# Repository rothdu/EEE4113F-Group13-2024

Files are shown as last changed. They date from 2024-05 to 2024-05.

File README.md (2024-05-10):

# UCT EEE4113F Group 13 2024

## Project description

This project involved the production of a camera-trap module for research on red-winged starlings at the University of Cape Town. The camera trap was designed to be stationed at the bird nests. Core requirements were motion-triggered photography, long-lasting battery life, and access to the module without disturbing the nests.

## Navigating the repository

circuit-schematics: shematics for the electronic hardware design
final-report: latex source code for the final project report
literature-review: latex source code for the project liteature review
firmware: firmware source code for the firmware development process and final implementation
sample-code: some sample code used to test the device hardware

## Contributing

This project will be drawn to a close after 15 May 2024.

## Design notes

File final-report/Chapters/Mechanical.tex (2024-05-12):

% ----------------------------------------------------
% Literature Review
% ----------------------------------------------------
\documentclass[class=report,11pt,crop=false]{standalone}
\input{../Style/ChapterStyle.tex}
\input{../FrontMatter/Glossary.tex}
\begin{document}
\ifstandalone
\tableofcontents
\fi
% ----------------------------------------------------
\chapter{ Mechanical Casing and Housing (MRBMAT004)\label{ch:mechanical}}
% \epigraph{}%
    % {\emph{---Carl Sagan}}
% \vspace{0.5cm}
% ----------------------------------------------------

% Before we even start on the first point, we should have a brief intro to talk about what it is we are doing. 
% Before this in chapter 1 will be our problem statement. 
% This is what I suggest: This literature delves into previous research articles pertaining to wildlife monitoring and related fields to better understand the approach that needs to be taken to design an effective camera module. This review will look into existing solutions (both the successes and failures). Data acquisition methods were also investigated. Integration of camera traps with IoT, sensing and power supply requirements were researched as well as looking into camera traps being situated in an urban setting with the risk of theft or damage from weather conditions. 
%Chapter 
%Mechanical Casing and Housing
\section{Introduction}
This section covers the mechanical case designs crafted for the the remote surveillance system deployed at the the Starlings’ nests located within the University of Cape Town for Sally who works at the Fitz Patrick Institute. The goal for this project was enhance nest surveillance through innovative technological solutions. These enclosures serve as the protective shell for our electronic components, safeguarding them against the elements while ensuring optimal functionality. By providing robust protection against environmental factors such as moisture, dust, and temperature fluctuations, the mechanical cases play a crucial role in the reliability and longevity of the surveillance system.
\newline

The surveillance system addresses existing challenges and gaps in current methods of monitoring bird nests by providing real-time data collection, minimizing disturbance to nesting birds, and enabling remote observation capabilities. Traditional nest monitoring methods often rely on manual observation, which can be time-consuming, labour-intensive, and disruptive to nesting birds. Our system offers a non-invasive alternative that allows researchers to gather valuable data without causing undue stress to the bird population.
\newline

The mechanical cases discussed in this section will house the Transmitter and Receiver circuitry systems that aim to solve the surveillance of the nests. This section discusses the design decisions, material choices and processes undertaken to realise the ‘final’ prototype. 
A comprehensive breakdown of the design processes, material choices, and iteration phases involved in the development of the mechanical cases. Exploring the intricacies of each design iteration, discussing the rationale behind design decisions and the challenges encountered during the prototyping process. Additionally, results for, testing and evaluation efforts, offering insights into the performance and effectiveness of the 'final' prototype. Finally, we will draw conclusions based on our findings and discuss potential avenues for future research and development in the field of avian monitoring technology.
\newline

\subsection{Requirements, Specifications, and Acceptable Prototype}
•	Size: 6x6x8cm\newline
•	Receiver case: handheld capability or mounting option\newline
•	Transmitter and receiver cases: safely house the sensor and power module circuits.\newline
•	Circuit protection from environmental conditions and theft prevention. \newline
•	Ease of access for maintenance and user experience.\newline
•	Compatibility with monitoring equipment.\newline
\newline

\section{Design Process}
\subsection{First Iteration Prototype}
The first iteration of the prototype was a simple rectangular box. During the initial stages of the design process, there was limited scope and clarity regarding the project requirements, prompting the development of a basic prototype to initiate discussions with stakeholders.
\newline

However, upon further refinement of the project specifications, it became evident that the initial rectangular design did not align with Sally's requirements, particularly in terms of size. The dimensions of the prototype were arbitrary and did not meet the specified 6x6x8cm dimensions. This discrepancy highlighted the need for clearer communication and adherence to design specifications from the onset of the project.
\newline

Additionally, the choice of PLA material for the prototype was based on availability, without consideration of alternative materials such as PETG, which offers superior properties for this application. The transition to PETG was later explored to address concerns related to material durability and performance.
\newline

One notable feature of the first iteration was the inclusion of a sliding mechanism for the open/close function. While this mechanism provided ease of access to the internal components, it posed challenges in terms of sealing effectiveness against moisture, dust, and water ingress. This limitation underscored the importance of robust sealing methods to ensure environmental protection and longevity of the electronic components housed within the enclosure.
\newline

Furthermore, the rectangular shape of the prototype presented challenges in airflow management, potentially leading to airflow turbulence or restrictions within the enclosure. While passive cooling solutions could be employed, such as ventilation holes, the design lacked provisions for active cooling mechanisms, which may be necessary to maintain optimal operating temperatures for sensitive electronics.
\newline

Despite these limitations, the rectangular design demonstrated efficiency in space utilization, offering maximum volume for component placement and organization. Moreover, its geometric simplicity facilitated ease of fabrication, reducing manufacturing complexity and costs associated with more intricate shapes.
\newline

Overall, the first iteration prototype served as a valuable learning experience, highlighting the importance of clear requirements definition, material selection, sealing methods, and considerations for airflow management in the design process. These insights informed subsequent iterations towards the development of a more refined and functional final prototype.
\newline

\subsection{Second Iteration}
The second iteration resembled a pitched roof house. This design idea was perfect until the size constraints were brought forth. Secondly, the pitched roof also limits and reduces the size of the already small dimensions of the specifications given by Sally: 6x6x8cm. 
\newline
This design had ventilation holes and forced cooling using a fan was considered. This fan would require a timer and trigger signal. This design had better airflow management as it promoted natural convection through the ventilation peaks at the peak without the need for additional cooling. The pitched roof enclosures blend seamlessly into outdoor environments, providing camouflage and enhancing the overall aesthetic appeal. However, concerns arose regarding the practicality of this design, particularly regarding size constraints and the need for additional cooling mechanisms as a fan would put added strain on the power supply and increase power losses.
\newline

\subsection{Material used}
% https://all3dp.com/2/plavsabsvspetgdifferencescompared/#google_vignette  
PLA, ABS and PETG are the most popular and readily available filaments out there. However, they are not equally suitable for every printing job as they have different qualities. All these comparisons were found from this non-scholarly article: https://all3dp.com/2/plavsabsvspetgdifferencescompared/#google_vignette
\newline

\subsubsection{PLA (Polylactic Acid)}
PLA is a widely used 3D printing material known for its ease of printing and low cost. Derived from renewable sources like corn starch, PLA is considered environmentally friendly, although it is more accurately described as industrially compostable rather than biodegradable. Its benefits include easy printing with no clogging issues, low print temperature, and affordability. However, PLA tends to deform or melt in high heat, making it unsuitable for heat resistant applications. It is also brittle and less sturdy compared to materials like ABS or PETG, making it better suited for aesthetic uses rather than mechanical ones.
\newline

\subsubsection{ABS (Acrylonitrile butadiene styrene)}
ABS (Acrylonitrile Butadiene Styrene) is a durable thermoplastic commonly used in 3D printing, injection molding, and machining. While it offers increased durability and resistance to water compared to PLA, it can emit unpleasant fumes during printing. ABS is known for its strength, toughness, and heat resistance, making it suitable for everyday items. However, it may degrade over time when exposed to prolonged moisture, and it is prone to dust accumulation. Despite its drawbacks, ABS can be easily finished post printing using acetone, making it suitable for aesthetic prints.
\newline

\subsubsection{PETG (Polyethylene terephthalate glycol)}
PETG is a popular choice for applications requiring food safety due to its excellent material properties. While it offers superior water resistance compared to PLA and ABS, printing PETG can be challenging due to its tendency to string during printing. PETG is known for its durability, impact resistance, and UV resistance, making it suitable for outdoor applications. However, it is prone to scratching and requires high printing temperatures, which contribute to stringing issues. Overall, PETG is widely regarded as a food safe filament with excellent mechanical properties.
\newline

Comparisons
\begin{table}[h]
\centering
\begin{tabular}{|>{\raggedright\arraybackslash}p{0.25\linewidth}|>{\raggedright\arraybackslash}p{0.25\linewidth}|>{\raggedright\arraybackslash}p{0.25\linewidth}|>{\raggedright\arraybackslash}p{0.25\linewidth}|}
\hline
 & \textbf{PLA} & \textbf{ABS} & \textbf{PETG} \\ \hline
Temperature & 180-220°C & 210-250°C & 220-250°C \\ \hline
Heated Bed Required & No & 210-250°C & 220-250°C \\ \hline
Enclosure & Does not require an enclosure & ABS is quite susceptible to drafts. Would benefit from an enclosure, to prevent warping and cracking & Does not require an enclosure \\ \hline
Post Processing & Filling, sanding, and priming are the primary methods. There are no safe chemical agents. & Easy to smooth out ABS using acetone & Ethyl acetate can be used to smooth PETG. Filling, sanding, and priming also work \\ \hline
Strength and Durability & Low-to-medium strength filament given its low heat and chemical resistance. & Medium-to-high strength filament, as it will sooner bend than break and has a higher impact, heat, and chemical resistance than PLA. & Medium-to-high strength filament. Mostly like ABS but is superior in strength \\ \hline

\end{tabular}
\end{table}

\begin{table}
    \centering
    \begin{tabular}{|>{\centering\arraybackslash}p{0.25\linewidth}|>{\centering\arraybackslash}p{0.25\linewidth}|>{\centering\arraybackslash}p{0.25\linewidth}|>{\centering\arraybackslash}p{0.25\linewidth}|} \hline 
Toxicity and Odour & Low odour and no toxicity & Has considerable odour and toxicity. & No odour or toxicity \\ \hline
Best Use Cases & Applications that do not have any specific functional requirements. & Often used in functional items that are used frequently or need to be durable. E.g. Drone frame & Excellent for items in contact with food and UV exposure, great for functional parts \\ \hline
    \end{tabular}
    \caption{3D prints filaments Comparison}
    \label{tab:my_label1}
\end{table}

\subsection{Dual and Single enclosure considerations}
In evaluating enclosure design options, a thorough analysis reveals the nuanced advantages of single and dual enclosure configurations. Single enclosures offer notable benefits such as efficient space utilization, simplified installation procedures, streamlined maintenance workflows, and potential cost savings due to component consolidation. However, they also pose challenges in thermal management, necessitating meticulous attention to airflow dynamics and heat dissipation strategies. Furthermore, comprehensive dustproofing measures are imperative to mitigate the risk of contamination and ensure long-term reliability.
\newline

Conversely, dual enclosure setups introduce unique advantages that contribute to the overall resilience and adaptability of the surveillance system. The modular nature of dual enclosures facilitates enhanced system flexibility, allowing for seamless component replacement, upgrades, or reconfigurations without disrupting the entire system. Moreover, the isolation of components within separate enclosures minimizes the risk of interference or contamination, ensuring optimal performance and reliability. The redundancy provided by dual enclosures offers an added layer of security, ensuring continuous operation even in the event of enclosure failure or malfunction.
\newline

Additionally, the customization potential inherent in dual enclosures enables tailored solutions to meet specific application requirements or environmental conditions. From optimized thermal management strategies to tailored dustproofing mechanisms, dual enclosures provide a versatile platform for finetuning system performance and resilience. By segregating components based on thermal characteristics, dual enclosures facilitate more effective heat distribution and dissipation, mitigating the risk of localized overheating and component degradation.
\newline

Furthermore, the independent sealing mechanisms of dual enclosures simplify dustproofing efforts, allowing for targeted measures to prevent dust ingress and contamination. By customizing dust filters and seals for each enclosure, the overall reliability and longevity of the surveillance system are enhanced, ensuring consistent performance even in harsh or dusty environments.

\subsection{Shape Considerations}
Each shape offers unique advantages and disadvantages, influencing space efficiency, aerodynamics, aesthetics, manufacturing complexity, and application-specific requirements.
\newline

Rectangular enclosures excel in efficient space utilization and ease of manufacture, making them suitable for accommodating complex electronic assemblies. However, they may lack optimal aerodynamics and aesthetic appeal compared to other shapes.
\newline

Cylindrical enclosures distribute stress more evenly and offer 360-degree access, making them robust and versatile for various applications. Yet, they may suffer from space inefficiency and manufacturing complexity.
\newline

Tapered or sloped enclosures prioritize improved aerodynamics and aesthetic appeal, optimizing space utilization while posing challenges in design complexity and manufacturing.

\section{Final Design Prototype}
The implementation of two separate electronic enclosure designs for the transmitter and receiver subsections was pivotal in addressing thermal concerns and meeting the distinct requirements of each subsystem. This separation not only improved temperature management but also allowed for increased airflow within each enclosure. Furthermore, considering that the transmitter and receiver subsystems are exposed to different environmental conditions and demand varied parameters for system longevity, this tailored approach ensured optimal performance and durability.
\newline

\subsection{Transmitter Case}
The final design for the mechanical cases for the transmitter subsection was chosen to be a rectangular box, carefully crafted to optimise functionality and environmental protection. It consisted of ventilation holes strategically placed to promote aeration and better airflow management, the design aimed to maintain optimal operating conditions for the enclosed components. Four vents were positioned at the base of the enclosure, each with a 5mm diameter and spaced 30mm apart, allowing air to enter from distinct locations. To prevent ingress of pests, debris, and dust, mesh screen filters covered these vents, while also minimizing the entry of water.
\newline

Four rectangular extrusions, situated 9mm above the base of the box, provided mounting or adhesive points for the Vero boards. This elevated placement reduced contact with any water that might enter through the base vents, ensuring the integrity of the components. Moreover, this design allowed for sufficient space for cool air to circulate around the boards.
\newline
\newline
\begin{figure}[H]
    \centering
    
    \caption{Solid works sensor design}
    \label{fig:enter-label3}
\end{figure}

To further enhance thermal management, aluminium heatsinks were strategically placed next to resistive and heat prone components. The orientation of the heatsink fins facing vertically upwards facilitated the natural convection process, whereby warm air rises. This directed the heat away from the components and towards the top of the enclosure. This is because warm air has lower density than cold air hence it rises. 
\newline

Additionally, three vents on either side of the box were incorporated to facilitate the removal of warm air from within the enclosure. This prevented the accumulation of warm air and the formation of a low-pressure cell, ensuring efficient airflow throughout the enclosure.
\newline

To tightly seal the enclosure a lid screw was used to minimise dust and water which was better than the sliding open/close mechanism used before.
\newline
For water and moisture management, a desiccant, silica gel was used to remove or absorb moisture from the electronic enclosure.
\newline

\subsection{Safety mechanisms and waterproof}
Mounting the rectangular enclosure is crucial for both practical functionality and ensuring safety and security. By rigidly attaching the enclosure to a stable structure like a wall or pole, it reduces the risk of unauthorized access to its internal components. This means it is much harder for people without permission to tamper with or steal the system. The act of mounting also acts as a strong deterrent against theft or vandalism, as it makes it clear that the system is secure and not easily removable. Additionally, securely mounting the enclosure ensures it can withstand external forces like wind or impact, making it more durable. It also helps the system comply with safety regulations, ensuring it meets industry standards. Adding features like tamper-resistant mechanisms further enhances security, making it even harder for unauthorized access. Overall, mounting the rectangular enclosure not only serves practical purposes but also plays a vital role in protecting the system and ensuring it functions effectively for a long time.
Mounting the enclosure was deemed a superior safety and security measure, particularly due to the elevated and often remote locations of Starlings' nests, where human access is infrequent. Opting for mounting over traditional locking mechanisms offers a practical solution, ensuring the system's protection without the complexities associated with locks. By rigidly attaching the enclosure to a stable structure, such as a wall or pole, the system's integrity is effectively preserved, mitigating the risk of tampering or theft. This approach not only enhances security but also aligns with the practical constraints of the surveillance environment, where accessibility is limited.

\begin{figure}[H]
    \centering
    
    \caption{Starlings bird Nest Position}
    \label{fig:enter-label2}
\end{figure}

In the ongoing development of the electronic enclosure, a transition has been made from a sliding open/close mechanism to a lid screw configuration. This upgrade aims to provide a more robust closure, effectively minimizing the intrusion of dust and water, while also enhancing security for the enclosed electronics.
\newline

% \newline
\begin{figure}[H]
    \centering
    
    \caption{SolidWorks lid design}
    \label{fig:enter-label3}
\end{figure}

Additionally, to address water and moisture management within the enclosure, silica gel desiccant packs have been integrated into the design. These packs serve as an effective solution for moisture absorption, ensuring the internal environment remains dry and conducive to the optimal functioning of the electronic components. Furthermore, the potential addition of cotton alongside the silica gel desiccant packs can provide an extra layer of moisture protection, especially in environments with high humidity levels or where condensation may occur. Cotton's ability to absorb excess moisture and function as a buffer between electronic components and desiccant packs offers additional assurance against moisture infiltration.
\newline

\subsubsection{Material of Choice}
PETG was the material of choice for the enclosure. PETG offers UV resistance, ensuring the enclosure's structural integrity and optical clarity under prolonged sunlight exposure. Its weather resistance enables it to withstand extreme temperatures, both cold and hot, without compromising its mechanical properties. PETG's strength and loadbearing capacity make it suitable for housing electronic components securely. Importantly, PETG is non-toxic and does not emit harmful gases, aligning with your sustainability goals. Additionally, its recyclable nature promotes responsible material usage, further enhancing the project's sustainability. 
\newline

There were two enclosures designed for the transmitter subsection housing, one for the power module and the other for the sensing circuitry discussed in the other two sections of the report. The dual enclosure method was implemented based on the advantages discussed above. Moreover, it allowed for modular design for each of the systems’ requirements. 
\newline

The power enclosure had all the design considerations discussed above: a lid screw, four vents at the bottom, three on either side of the box, four extrusions for Veroboard, and lastly four exterior extrusions with holes for mounting.
\newline
\begin{figure}[H]
    \centering
    
    \caption{The Power system enclosure}
    \label{fig:enter-label3}
\end{figure}

%%%add the power house
 
The sensing circuitry housing had the same design as the housing for power and had additional openings for the camera sensor, 5 PIR sensors and the 2 LDRs, so that surveillance can be achieved remotely while the housing is mounted. The housings are to be mounted close to the nests which would be easy given where the nests are on campus. 
 %%add thiyashans hous

\begin{figure}[H]
    \centering
    
    \caption{The Sensor system enclosure}
    \label{fig:enter-label4}
\end{figure}

\subsection{Receiver Case}
The receiver module material was chosen to be ABS, since it is durable and can be used for consumer daily needs. ABS’ smooth texture and durability and impact resistance made it a suitable material choice for the handheld receiver module.
\newline

The enclosure design included a carefully cutout area to display the LCD output, with a detachable clip side serving as a convenient access point for buttons, eliminating the need for enclosure disassembly. 
\newline

Additionally, a removable latch-sliding mechanism provided port access and simplified battery replacement, as the battery was located on the sliding mechanism side. The generous opening on the sliding mechanism side facilitated effortless battery changes. Prioritizing portability, the enclosure was designed to be handheld, with a compact size ensuring easy readability of LCD display information. This module was bought and had to be assembled and cut the LCD screen part. The removable clip side for the button side made this case attractive as it would be easier to cut holes on the clip or just remove the clip when wanting to access and interface with the buttons. The screw assembled and joined case ensured secure assembly, featuring extrusions for Veroboard placement and a divider allowing for the partitioning of different circuit systems within the enclosure.
\newline

The receiver module did not have specific dimensions but was required to accommodate an 8x4cm LCD area and house the receiver circuitry and its power requirements. This was a single enclosure, and was chosen for the reasons already outlined above, such as efficient space utilization, simplified installation procedures, streamlined maintenance workflows, and potential cost savings. The enclosure design allowed for better airflow, with the removable latch sliding mechanism and LCD cutout contributing to ventilation. Storage conditions were expected to be room temperature, with user requirements limited to handheld, LCD display output and button access, while ensuring circuit integrity and weight support.

\begin{figure}[H]
    \centering
    
    \caption{The receiver enclosure}
    \label{fig:enter-label5}
\end{figure}

\section{Acceptable Test Procedures}
 
1. Material Durability and Impact Resistance Test:
 Drop tests were conducted from various heights to assess the durability and impact resistance of the ABS and PETG materials. Observations were made for any signs of damage, cracking, or deformation after each drop test. None were found so passed. 
 \newline

2. Ventilation and Airflow Test:
    The enclosure designs with ventilation holes and extrusions were 3D printed. Temperature and humidity sensors were used to measure airflow and temperature distribution within the enclosures.
    The effectiveness of the ventilation system in maintaining optimal operating conditions for enclosed components was evaluated. The system integration with the sensing subsystem could not be done due to time constraints so this test could not be performed, hence undeterminable.
    \newline

3. Weather Resistance Test:
    The 3D-printed enclosures were subjected to temperature and humidity variations in a controlled environment. Exposure to UV light was done by placing the enclosures on the window for days. The enclosures were assessed for any signs of degradation, discoloration, or moisture ingress after exposure. None were found so passed.
    \newline

4. Lid Screw Seal Integrity Test:
    The enclosures were 3D printed with lid screw mechanisms. The lid and housing were mated on SolidWorks to ensure that they fit together through simulation. The lid was successfully screwed to the enclosure, although it had to be cut since Solidworks scaled the enclosures. Passed.
    \newline

5. Moisture Management Test:
 Silica gel desiccant packs and cotton were placed inside the 3D-printed enclosures. Moisture levels inside the enclosures were monitored over time using moisture indicators. The effectiveness of moisture absorption and management by the desiccant packs and cotton was verified. The system integration with the sensing subsystem could not be done due to time constraints so this test could not be performed, hence undeterminable.
\newline

6. Portability and Handheld Use Test:
The 3D-printed enclosures were assembled, and the bought design for handheld use was assessed. The comfort and ease of handling were evaluated, ensuring easy access to buttons and readability of the LCD display. Passed.
\newline

7. Assembly and Disassembly Test:
    The 3D-printed enclosures were assembled and disassembled multiple times to assess the ease of assembly and accessibility to internal components. Wear or damage to the enclosure components during assembly and disassembly was checked. Passed
    \newline

8. Mounting and Security Test:
 The 3D-printed enclosures were attached to stable structures using mounting brackets or adhesive mounts. Force or pressure was applied to the mounted enclosures to simulate external impacts, verifying their stability and security. Passed. 
 \newline

9. Functionality and Compatibility Test:
Electronic components and power sources were installed inside the 3D-printed enclosures. The functionality of the LCD display, buttons, and other components was evaluated to ensure proper operation. Compatibility with the specified electronic components and power requirements was verified.
Failed. The enclosures were scaled down by the Prusa slicer and were not the same dimensions as given on solid works, hence the printed enclosures were small, and the lid had to be cut as it was not scaled to fit the small enclosures. 
\newline

% ----------------------------------------------------
\ifstandalone
\bibliography{../Bibliography/References.bib}
\printnoidxglossary[type=\acronymtype,nonumberlist]
\fi
\end{document}
% ----------------------------------------------------

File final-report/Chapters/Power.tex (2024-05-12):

% ----------------------------------------------------
% Literature Review
% ----------------------------------------------------
\documentclass[class=report,11pt,crop=false]{standalone}
\input{../Style/ChapterStyle.tex}
\input{../FrontMatter/Glossary.tex}
\begin{document}
\ifstandalone
\tableofcontents
\fi
% ----------------------------------------------------
\chapter{ Power Submodule
(PRMRUV001)\label{ch:literature}}
\section{Power Submodule}

In the submodule, it will detail the supply of power to the entire system as a whole. It serves as the heartbeat of the project and is very important. It deals with in a broader scope, the charging and storage of power that can be consumed, as well voltage regulation to a voltage that is suitable for the other submodules that need to draw power.

\section{Requirement Analysis}

In order to design an effective power submodule, analysis of what needs to be achieved in this submodule needs to be carried out extensively. Meeting the user’s requirements are the main objectives. However, in order to meet these requirements well, functional requirements and specifications of the proposed solution needs to be detailed. This can be found below.

\subsection{User Requirements}

These requirements are set out by the client, Sally. In order for the submodule to be a success it would need to meet the requirements. 

\begin{table}
\centering

\begin{tabular}{|>{\raggedright\arraybackslash}p{0.2\linewidth}|>{\raggedright\arraybackslash}p{0.8\linewidth}|}
\hline
\textbf{UR01} & \textbf{Grid Independent} \\
\hline
\textbf{Requirement} & Sally requires the device to charge without the grid mains power supply. \\
\hline
\textbf{Description} & The power system is the heartbeat of the camera trap device, and its awkward placements in nests make it difficult for the device to always be charged using the grid main power supply. Hence, Sally’s requirement for the device to be charged and powered using an alternative power supply method. \\
\hline
\textbf{Refined by} & FR01 \\
\hline

\end{tabular}

\end{table}

\begin{table}
\centering

\begin{tabular}{|>{\raggedright\arraybackslash}p{0.2\linewidth}|>{\raggedright\arraybackslash}p{0.8\linewidth}|}
\hline
\textbf{UR02} & \textbf{Reliability} \\
\hline
\textbf{Requirement} & Sally requires a device that has a reliable power supply.  \\
\hline
\textbf{Description} & It was made clear that the monitoring of these birds is very important and so is the data recorded. Hence, it is vitally important that the device continuously has good reliable power supply to operate to avoid data capturing loss. \\
\hline
\textbf{Refined by} & FR02 \\
\hline

\end{tabular}

\end{table}

\begin{table}
\centering

\begin{tabular}{|>{\raggedright\arraybackslash}p{0.2\linewidth}|>{\raggedright\arraybackslash}p{0.8\linewidth}|}
\hline
\textbf{UR03} & \textbf{Sizing} \\
\hline
\textbf{Requirement} & Sally requires the device to be light and compact. \\
\hline
\textbf{Description} & The starling birds are very sensitive and particularly do no like foreign objects in their space. Furthermore, the nests that are to be monitored are small and light. Hence, the need for the Power submodule to be as light and compact as possible. \\
\hline
\textbf{Refined by} & FR03 \\
\hline

\end{tabular}

\end{table}

\subsection{Functional Requirements}

These requirements are outlined by the designer in order to make the users requirements more detailed. This in turn makes the submodule more coherent and lay out guidelines to follow so that the submodule can be a success.

\begin{table}
\centering

\begin{tabular}{|>{\raggedright\arraybackslash}p{0.2\linewidth}|>{\raggedright\arraybackslash}p{0.8\linewidth}|}
\hline
\textbf{FR01-1} & \textbf{Rechargeable Battery} \\
\hline
\textbf{Requirement} & The system battery needs to be able to support recharging from sources such as solar power. \\
\hline
\textbf{Refines} & UR01 \\
\hline
\textbf{Refined by} & UR01-S01 \\
\hline
\textbf{Verification} & N/A \\
\hline

\end{tabular}

\end{table}

\begin{table}
\centering

\begin{tabular}{|>{\raggedright\arraybackslash}p{0.2\linewidth}|>{\raggedright\arraybackslash}p{0.8\linewidth}|}
\hline
\textbf{FR01-2} & \textbf{Solar Panel} \\
\hline
\textbf{Requirement} & The system requires a solar panel as a form of solar power generation to charge the battery. \\
\hline
\textbf{Refines} & UR01 \\
\hline
\textbf{Refined by} & UR01-S02 \\
\hline
\textbf{Verification} & ATP01 \\
\hline

\end{tabular}

\end{table}

\begin{table}
\centering

\begin{tabular}{|>{\raggedright\arraybackslash}p{0.2\linewidth}|>{\raggedright\arraybackslash}p{0.8\linewidth}|}
\hline
\textbf{FR02-1} & \textbf{Circuit Protection} \\
\hline
\textbf{Requirement} & The system battery needs to be able to support recharging from sources such as solar power. \\
\hline
\textbf{Refines} & UR01 \\
\hline
\textbf{Refined by} & UR01-S03 \\
\hline
\textbf{Verification} & ATP02, ATP03 \\
\hline

\end{tabular}

\end{table}

\begin{table}
\centering

\begin{tabular}{|>{\raggedright\arraybackslash}p{0.2\linewidth}|>{\raggedright\arraybackslash}p{0.8\linewidth}|}
\hline
\textbf{FR02-2} & \textbf{Voltage Conversion} \\
\hline
\textbf{Requirement} & The primary requirement is to provide a steady regulated output voltage of 5V. \\
\hline
\textbf{Refines} & UR02 \\
\hline
\textbf{Refined by} & UR02-S02 \\
\hline
\textbf{Verification} & ATP04 \\
\hline

\end{tabular}

\end{table}

\begin{table}
\centering

\begin{tabular}{|>{\raggedright\arraybackslash}p{0.2\linewidth}|>{\raggedright\arraybackslash}p{0.8\linewidth}|}
\hline
\textbf{FR02-4} & \textbf{Voltage ripple} \\
\hline
\textbf{Requirement} & The voltage ripple must be within acceptable limits, ideally as low as 100mV. \\
\hline
\textbf{Refines} & UR02 \\
\hline
\textbf{Refined by} & - \\
\hline
\textbf{Verification} & ATP05 \\
\hline

\end{tabular}

\end{table}

\begin{table}
\centering

\begin{tabular}{|>{\raggedright\arraybackslash}p{0.2\linewidth}|>{\raggedright\arraybackslash}p{0.8\linewidth}|}
\hline
\textbf{FR03-1} & \textbf{Size Restriction} \\
\hline
\textbf{Requirement} & The power submodule must fit in the casing dimensions stipulated in the casing submodule. \\
\hline
\textbf{Refines} & UR03 \\
\hline
\textbf{Refined by} & UR03-S01 \\
\hline
\textbf{Verification} & ATP06 \\
\hline

\end{tabular}

\end{table}

\section{Design Specifications}

In this chapter, we will specify how the requirements will be met as well as the engineering principles that will be used.

\begin{table}
\centering

\begin{tabular}{|>{\raggedright\arraybackslash}p{0.2\linewidth}|>{\raggedright\arraybackslash}p{0.8\linewidth}|}
\hline
\textbf{UR01-S01} & \textbf{Rechargeable Battery} \\
\hline
\textbf{Detail} & The batteries that will be used will be the 4.2V Lithium ion 18650 8800 mAh battery.  \\
\hline
\textbf{Refines} & FR01-1 \\
\hline
\textbf{Verification} & Battery selection in design choices section. \\
\hline

\end{tabular}

\end{table}

\begin{table}
\centering

\begin{tabular}{|>{\raggedright\arraybackslash}p{0.2\linewidth}|>{\raggedright\arraybackslash}p{0.8\linewidth}|}
\hline
\textbf{UR01-S02} & \textbf{Solar Panel} \\
\hline
\textbf{Detail} & The solar panel chosen must be able to provide minimum voltage required to charge the battery.  \\
\hline
\textbf{Refines} & FR01-2 \\
\hline
\textbf{Verification} & N/A \\
\hline

\end{tabular}

\end{table}

\begin{table}
\centering

\begin{tabular}{|>{\raggedright\arraybackslash}p{0.2\linewidth}|>{\raggedright\arraybackslash}p{0.8\linewidth}|}
\hline
\textbf{UR02-S01} & \textbf{Circuit Protection} \\
\hline
\textbf{Detail} & The submodule must include an over voltage protection circuit as well as well as a reverse polarity protection circuit in order to protect the components of the submodule.  \\
\hline
\textbf{Refines} & FR02-1 \\
\hline
\textbf{Verification} & ATP02, ATP03 \\
\hline

\end{tabular}

\end{table}

\begin{table}
\centering

\begin{tabular}{|>{\raggedright\arraybackslash}p{0.2\linewidth}|>{\raggedright\arraybackslash}p{0.8\linewidth}|}
\hline
\textbf{UR02-S02} & \textbf{Voltage Conversion} \\
\hline
\textbf{Detail} & The submodule will include a buck converter that will regulate the voltage down to a steady 5V.  \\
\hline
\textbf{Refines} & FR02-2 \\
\hline
\textbf{Verification} & ATP7 \\
\hline

\end{tabular}

\end{table}

\begin{table}
\centering

\begin{tabular}{|>{\raggedright\arraybackslash}p{0.2\linewidth}|>{\raggedright\arraybackslash}p{0.8\linewidth}|}
\hline
\textbf{UR03-S01} & \textbf{Sizing} \\
\hline
\textbf{Detail} & The submodule must fit in a casing of dimensions 60 x 60 x 80 mm \\
\hline
\textbf{Refines} & FR03-1 \\
\hline

\end{tabular}

\end{table}

\section{Acceptance Test Procedure (ATP’s)}

The acceptance test procedure will ensure that the design meets its intended performance. The procedure involves defining figures of merit, designing experiments to evaluate these metrics, and establishing acceptable performance standards.

\begin{table}
\centering

\begin{tabular}{| l  |l  |>{\raggedright\arraybackslash}p{0.3\linewidth}|>{\raggedright\arraybackslash}p{0.3\linewidth}|}
\hline
\textbf{ATP ID} & \textbf{ATP name} & \textbf{Figures of merit} & \textbf{Test} \\
\hline
\textbf{ATP01} & Solar Panels & Verify that the solar PV panels provide the minimum specified voltage for charging the battery packs.

  & Place Solar under various sun intensities and measure the produced voltages. \\
\hline
\textbf{ATP02} & Over Voltage Protection & Verify that the protection circuits work when they need to. & We can test this by applying a high voltage to the over voltage protection circuit. \\
\hline
\textbf{ATP03} & Reverse Polarity Protection. & Verify that the protection circuits work when they need to. & We can test this by applying a reverse bias current to the reverse polarity circuit. \\
\hline
\textbf{ATP04} & Voltage Regulation & This is about making sure the output voltage stays steady even when things change. We want to know if the converter can keep the voltage where we want it, no matter what's happening. & We'll suddenly change the load to see if the converter can keep the output voltage steady.

We'll watch the output voltage closely and check if it stays within a certain range of the desired voltage. \\
\hline
\textbf{ATP05} & Voltage ripple & We will perform this test to see that the voltage ripple is not exceeding our desired limits. & We can test this by connecting the output of the buck converter to the oscilloscope and using the measure function. \\
\hline
\textbf{ATP06} & Sizing & We will test to see that the power submodule Veroboard can fit in the casing. & We can test this by building our circuits on Veroboard and placing it in the casing. \\
\hline

\end{tabular}

\end{table}

\section{Design Choices}

In order to make design choices, we first have to understand how much power is required from the other submodules. This value is no more than 10 W.

\subsection{Battery choice}

There are multiple battery possibilities. However, we need to first calculate the required battery capacity in order to get a good fit. Using the table above we can allocate excess power and work of the required power being 20W. We can also assume we that we want the battery to operate for 12 hours, just enough time for the solar to start again.

We plan on using a five-battery pack rated at 4.2V each. The calculations are as follows:

Since the power required by the system was exaggerated, it is same to say that even with efficiency problems related to a battery, it would still be acceptable.

We can now analyse various batteries at similar rating as seen in the table below:

\begin{table}
\centering

\begin{tabular}{| l | l | l | l |}
\hline
  & \textbf{VRLA AGM Battery} & \textbf{Lead acid battery} & \textbf{Li-ion 18650} \\
\hline
\textbf{Type} & VRLA & LiFePO4  & Lithium ion \\
\hline
\textbf{Rated Voltage (V)} & 12 & 12 & 4.2 \\
\hline
\textbf{Rated Capacity (mAh)} & 7000 & 6000 & 8000 \\
\hline
\textbf{Size (mm)} & 151 x 65 x 95 & 152 x 65 x 97 & 65 x 20 x 20 \\
\hline
\textbf{Cost (R)} & 192 & 499 & 186 (Pack of 5) \\
\hline

\end{tabular}

\end{table}

 From the table above we can conclude our analysis on various types of batteries. With the VRLA AGM Battery, we can see that the rated capacity falls short of the required capacity as well as the rated voltage being too low. The lead acid battery follows the same suit and is very expensive making it a bad match. However, the Li-ion 18650’s seems to be the best match and the battery of choice. It falls withing the required capacity, has a rated voltage of 4.2V which when all are connected in series amount to 21V, and it is relatively affordable.

\subsection{Voltage Regulation}

The most crucial part of the power submodule is the voltage regulation. For this specific design, the other submodules only required a regulated voltage of 5V. This means that the voltage from the battery needs to be steeped down to that voltage of 5V. The various ways in which we can achieve that are detailed below:

\begin{table}
\centering

\begin{tabular}{| l | l | l | l |}
\hline
  & \textbf{L4940V5} & \textbf{CRE1S2405SC} & \textbf{Buck Converter} \\
\hline
\textbf{Input Voltage (V)} & 6.5 – 15 & 24 & 20 \\
\hline
\textbf{Output Voltage (V)} & 5 & 5 & 5 \\
\hline
\textbf{Output Current (A)} & 2.5 & 0.2 & Variable \\
\hline
\textbf{Complexity} & Easy & Easy & Complex \\
\hline
\textbf{Cost} & 28 & 57,07 & 20 \\
\hline

\end{tabular}

\end{table}

 From the table above we can make an inform decision in which methos we are going to use as our step-down regulator. We first analyse the L4940V5 voltage regulator, this does not fit well into the design because it outputs a max current that is high, and the input voltage will require a voltage divider in order for it to meet the specifications stated. The CRE1S2405SC is too expensive to use and also reflects no design thinking behind it. The buck converter using first principles can be tailored to fit any scenario and fits the design of the project best.

Hence, the buck converter using first principles is the best option.

\section{Power Submodule Design}

\subsection{Subsystem Block Diagram}

 \begin{figure}
     \centering
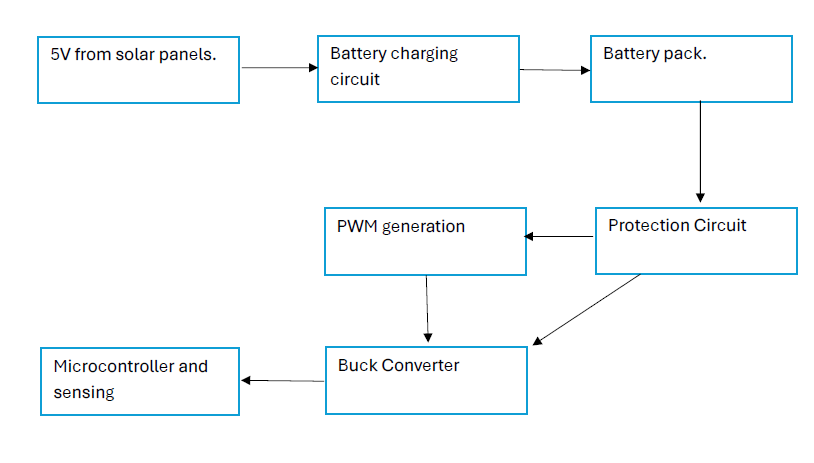
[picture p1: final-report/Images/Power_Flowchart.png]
     
     \caption{Flowchart of subsystem}
     \label{fig:enter-label}
 \end{figure}

\subsection{Pulse Width Modulation}

For this part of the submodule a 555 timer will be used to generate a pulse for the switch in the buck converter. The calculations of the parameters are as follows.

The circuit can be found below:
\begin{figure}
    \centering
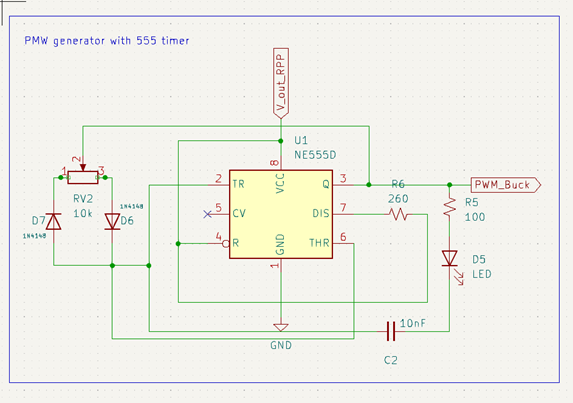
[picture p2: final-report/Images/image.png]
    
    \caption{PWM generator using a 555 timer.}
    \label{fig:enter-label}
\end{figure}

\subsection{Buck Converter (Voltage regulation)}

For this project, it is required that the designed system is efficient and can regulate the output voltage to 5V. The circuit parameters can be calculated, as shown below.

To explain how the selection of parameters occurred we will need to have a scenario/problem. 

Let's consider a scenario where we aim to design a DC-DC converter that converts a 20V DC input to a stable 5V DC output. We've chosen a switching frequency of 100 kHz. In addition, we want to maintain a current ripple of 0.5 and a voltage ripple of 10 mV for optimal performance.

\[Ripple\ current = \ \mathrm{\Delta}i_{L} = 0.5\ A\]

\[
{Therefore\ to\ find\ Inductor\ Value:}\]

\[
{L = \frac{V_{0}(1 - D)}{f_{s}\mathrm{\Delta}i_{L}}
}{Where:
}{V_{0} = 5V
}{D = \frac{V_{o}}{V_{in}} = \frac{5}{20} = 0.25
}{f_{s} = 100kHz}\]

\[Therefore\ from\ above\ the\ inductor\ value\ can\ be\ calculated:\]

\[
{L = \frac{5(1 - 0.25)}{(1000000)(0.5)} = 75\mu H}\]

\[Capacitor\ value\ is\ calculated\ using:\]

\[C = \frac{1 - D}{8L\left( \frac{\mathrm{\Delta}V_{o}}{V} \right)f^{2}} = \frac{1 - 0.25}{8(75\mu)\left( \frac{0.01}{5} \right)(100000)^{2}} = 62.5\mu F\]

 Component selection:

· Inductor value 75 uH

· Capacitor value 62.5 uF

The figure below shows the schematic of the designed circuit:
\begin{figure}
    \centering
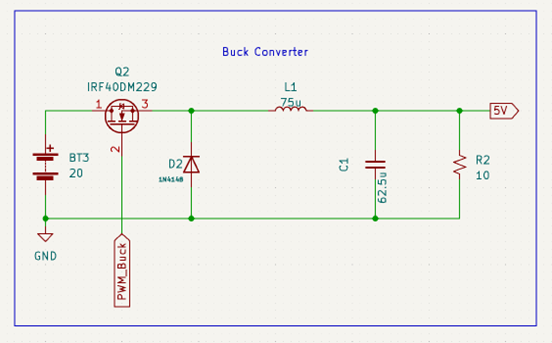
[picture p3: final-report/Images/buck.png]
    
    \caption{Schematic of buck converter}
\end{figure}

\subsection{Reverse Polarity Protection}

For this design, we simply needed to design a circuit that would provide reverse bias current protection. The simplest way to protect against this happening is to simply use a diode. The circuit can be found below.
\begin{figure}
    \centering
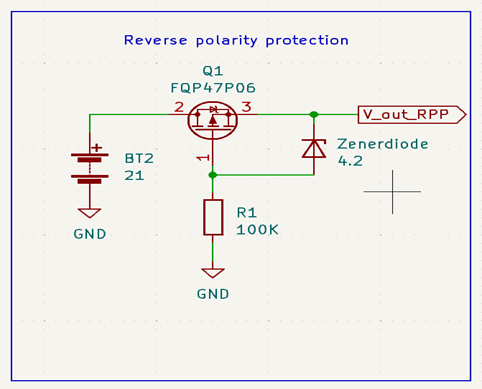
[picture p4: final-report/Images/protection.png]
    
    \caption{Reverse polarity schematic}
    \label{fig:enter-label}
\end{figure}

\subsection{Battery Charging Circuit}

For the purpose of the battery charging circuit being able to be charged by solar we took a generic input of Vsupply which is the voltage produced by the solar panels. The schematic of the charging circuit with over voltage protection can be found below.
\begin{figure}
    \centering
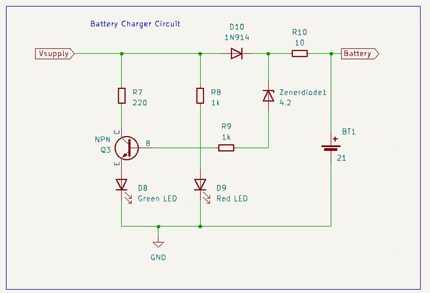
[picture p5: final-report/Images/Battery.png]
    
    \caption{Battery charging circuit with over voltage protection}
    \label{fig:enter-label}
\end{figure}

\subsection{Voltage Divider (Receiver)}

For the receiver, there is no need for much protection, just the basics. Hence, it was decided that a voltage regulator with a diode would be perfect for this case. Resistor values were calculated using the voltage divider rule. The schematic of the circuit is below:
\begin{figure}
    \centering
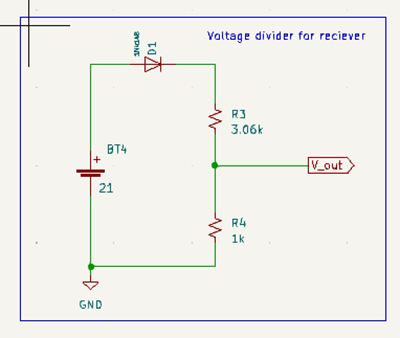
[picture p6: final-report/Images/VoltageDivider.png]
    
    \caption{Voltage divider for receiver}
    \label{fig:enter-label}
\end{figure}

\section{Testing and validation}

In this section we will be testing our circuits in order to make sure that they work and perform the way that it is intended to.

\subsection{Pulse width modulation.}

The PWM generator was constructed using the 555 timer and it was then connected to the oscilloscope and the output was captured as seen below.
\begin{figure}
    \centering
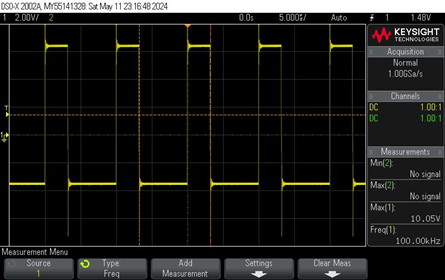
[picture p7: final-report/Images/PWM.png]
    
    \caption{PWM output}
    \label{fig:enter-label}
\end{figure}

As seen in the figure, the PWM output works as expected with a duty cycle of 25\%.

\subsection{Protection circuits}

The power protection circuits were then tested. With regards to over voltage protection circuit. We tested this by applying a high voltage to the over voltage protection circuit. The LED switched on to indicate that the voltage was high, and the circuit was then short circuited to ground, cutting of power to the rest of the circuitry.

With regards to the reverse polarity protection circuit. A reverse bias current was applied to the protection circuit. It was observed that the diode was then reverse bias and acted as an open circuit and no current flowed in the circuit. Hence, we can conclude that both protection circuits operated as expected.

\subsection{Voltage divider (Receiver)}

For this circuit, it was fairly simple to test. The voltage regulator was constructed and then tested by measuring the output. The circuit also provided reverse bias protection through the diode. The output was 5V as expected.

\subsection{Buck Converter / Integrated circuits}

To test the buck converter, a 20V supply voltage was applied at the input and the output was then recorded using an oscilloscope. The results were as expected, and the buck converter successfully outputted the desired 5V and shown below.
\begin{figure}
    \centering
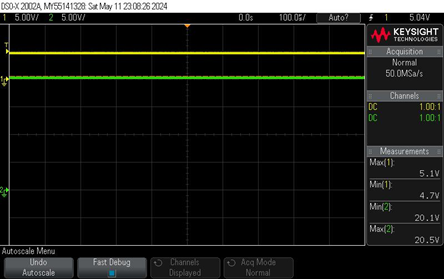
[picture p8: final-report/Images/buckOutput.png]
    
    \caption{Buck converter output}
    \label{fig:enter-label}
\end{figure}

\section{ATP Evaluation}

In this section, we revisit the ATP’s and evaluate their extent of success. This evaluation is tabulated below.

\begin{table}
\centering

\begin{tabular}{| l  |l  |l  |>{\raggedright\arraybackslash}p{0.3\linewidth}|}
\hline
\textbf{ATP ID} & \textbf{ATP name} & \textbf{Outcome} & \textbf{Details} \\
\hline
\textbf{ATP01} & Solar Panels & Undecided

  & This ATP test was not completed as a solar panel was not bought due to budget restrictions. \\
\hline
\textbf{ATP02} & Over Voltage Protection & Passed & The over voltage protection circuit worded and opened the circuit when voltage was too high. \\
\hline
\textbf{ATP03} & Reverse Polarity Protection. & Passed & We can test this by applying a reverse bias current to the reverse polarity circuit. \\
\hline
\textbf{ATP04} & Voltage Regulation & Passed  & The buck converter as well as the voltage divider for the receiver outputted 5V and worked as intended. \\
\hline
\textbf{ATP05} & Voltage ripple & Failed & The buck converter had a voltage ripple of 400 mV. \\
\hline
\textbf{ATP06} & Sizing & Failed. & The casing was small and when trying to fit the submodule in, the Veroboard fit but the 5-battery pack did not. \\
\hline

\end{tabular}

\end{table}

\section{Conclusion}

In conclusion, the main requirements of the power system submodule have been met and the power submodule was a success. It was a difficult process trying to account for all small details such as voltage ripple being a minimum but in essence the final design worked out well.

% ----------------------------------------------------
\ifstandalone
\bibliography{../Bibliography/References.bib}
\printnoidxglossary[type=\acronymtype,nonumberlist]
\fi
\end{document}
% ----------------------------------------------------

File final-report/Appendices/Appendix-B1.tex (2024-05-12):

\documentclass[class=report,11pt,crop=false]{standalone}
\input{../Style/ChapterStyle.tex}
\input{../FrontMatter/Glossary.tex}
\begin{document}
\ifstandalone
\tableofcontents
\fi
%------------------------------------------------------------

% \appendix{Evidence of GAs met}

\chapter{Evidence of GAs Met}

\section{PRMRUV001}

\centering
\begin{tabularx}{\textwidth}{|p{0.07\textwidth} p{0.2\textwidth} X|}

    \hline
    \textbf{GA} & \textbf{GA Description} & \textbf{Area GA is met} \\ \hline

    GA3 & Engineering Design & Chapter \ref{ch:power} (Power Chapter) details the development of the power supply for the Red-Winged Starling Nest Monitoring project. After engagement with project stakeholders, the requirements and specifications of the subsystem were anaylsed. A number of high-level design decisions were considered and detailed, followed by extensive testing of the subsystem on the project hardware. Finally, a number of acceptance test procedures were developed and performed. \\ \hline

    GA7 & Sustainability and Impact of Engineering Activity & The Red-Winged Starling Nest Monitoring works towards the sustainability of engineering activity by developing a tool for research in wildlife conservation. In addition, D-school lessons were attended where we actively participated in ethical design practices. \\ \hline

    GA8 & Individual, Team and Multidiscipliniary Working & The overall project encompassed extensive teamwork, including a collective analysis of the needs of the project stakeholders and a joint literature review. Much of this communication is viewable on the group's Microsoft Teams chat. Within the framework of the group project, individual work was done in the development of the power system subsystem, this is evident in the power submodule section of the final report. The group members encompassed a multidiscipliniary engineering team, with specialisations in Electrical Engineer, Electrical and Computer Engineering, and Mechatronics. The project also involved extensive engagement with ornothological researchers, who work outside of the engineering field. \\ \hline

    GA10 & Engineering Professionalism & Throughout the project, professional relationships and communication were maintained with the other group members, project stakeholders and project staff. All deliverables were presented on time. A schedule was made and stuck to in terms of being on time. \\ \hline

\end{tabularx}
\raggedright

\section{PLLTHI032}

\centering
\begin{tabularx}{\textwidth}{|p{0.25\textwidth} X|}

    \hline
    \textbf{Camera/Transmitter (CT) \& Receiver (R) Hardware (PLLTHI032)}  & \textbf{Area GA is met} \\ \hline

    GA3: Engineering Design & Chapter \ref{ch:hardware} discusses the development of the transmitter/camera and receiver modules for the Red-Winged Starling Nest Monitoring project. After speaking to the stakeholders, the user requirements, functional requirements and specifications were created and analysed, shown in section \ref{sc: HW_R_S}. Thereafter, the entire design process was documented and shown in section \ref{sc: HW_DP}. This was followed by a proposed final design and development of support circuitry, shown in section \ref{sc: HW_FD}. The power consumption was then measured in different operating modes, shown in section \ref{sc: HW_PC}. Finally, a number of acceptance test procedures were developed and performed, shown in section \ref{sc: HW_TR}. \\ \hline

    GA7: Sustainability and Impact of Engineering Activity & The Red-Winged Starling Nest Monitoring project works towards sustainability of engineering activity by creating a product for wildlife research and conservation.  In addition, the group attended D-School to develop skills on design approaches. \\ \hline

    GA8:Individual, Team and Multidiscipliniary Working & Throughout the project, teamwork was key in making sure the final product worked together harmoniously. This involved creating a joint literature review, along with communicating weekly on Microsoft Teams. Extensive discussions were conducted, with the main objective to find the perfect solution to meet the stakeholder requirements, as well as dividing the work into equal subsystems. Thereafter, individual work was conducted to develop the hardware subsystem of the camera/transmitter and receiver on my end. The members that fromed group 13 were of different engineering backgrounds such as Electrical Engineering, Electrical and Computer Engineering, and Mechatronics. Extensive research was conducted with ornothological researchers who are not involved in the engineering space. \\ \hline

    GA10: Engineering Professionalism & All submissions and activities were met including the final report and presentation. Professional relationships have also been maintained between colleagues. \\ \hline

\end{tabularx}
\raggedright

\section{DGMROB001}

\centering
\begin{tabularx}{\textwidth}{|p{0.25\textwidth} X|}

    \hline
    \textbf{GA}  & \textbf{Area GA is met} \\ \hline

    GA3: Engineering Design & Chapter \ref{ch:firmware} details the development of firmware for the Red-Winged Starling Nest Monitoring project. After engagement with project stakeholders, the requirements and specifications of the subsystem were anaylsed. A number of high-level design decisions were considered and detailed in section \ref{s:firmware-design-decisions}, followed by extensive testing of the subsystem on the project hardware. Finally, a number of acceptance test procedures were developed and performed, discussed in section \ref{s:firmware-atps}. The source code for the firmware is available in the \href{https://github.com/rothdu/EEE4113F-Group13-2024}{project repository} on GitHub. \\ \hline

    GA7: Sustainability and Impact of Engineering Activity & The Red-Winged Straling Nest Monitoring works towards sustainability of engineering activity by developing a tool for research in wildlife conservation. Activities at the UCT D-School worked towards engaging with stakeholders on this issue. A broad overview of the project is given in Chapters \ref{ch:introduction} and \ref{ch:problem-analysis}. The firmware developed for this purpose is discussed in \ref{ch:firmware}.\\ \hline

    GA8: Individual, Team and Multidiscipliniary Working & The overall project encompassed extensive teamwork, including a collective analysis of the needs of the project stakeholders and a joint literature review. Minutes from meetings and intra-team communications are viewable on the project group's Microsoft Teams chat. Within the framework of the group project, individual work was done in the development of the firmware subsystem. The group members encompassed a multidiscipliniary engineering team, with specialisations in Electrical Engineering, Electrical and Computer Engineering, and Mechatronics. The project also involved extensive engagement with ornothological researchers, who work outside of the engineering field. \\ \hline

    GA10: Engineering Professionalism & Throughout the project, professional relationships and communication were maintained with the other group members, project stakeholders and project staff. All deliverables were presented on time. \\ \hline

\end{tabularx}
\raggedright

\section{MRBMAT004}

\centering
\begin{tabularx}{\textwidth}{|p{0.07\textwidth} p{0.2\textwidth} X|}

    \hline
    \textbf{GA} & \textbf{GA Description} & \textbf{Area GA is met} \\ \hline

    GA3 & Engineering Design & Chapter  \ref{ch:mechanical} (mechanical casing and housing) details the development of the housing and the design decisions taken for the Red-Winged Starling Nest Monitoring project. After thorough research and engagement with project stakeholders, the user requirements, functional requirements, and specifications were created and analysed, as shown in the Mechanical casing and housing section.   The source code for the firmware is available in the \href{https://github.com/rothdu/EEE4113F-Group13-2024}{project repository} on GitHub.   \\ \hline

    GA7 & Sustainability and Impact of Engineering Activity & The Red-Winged Starling Nest Monitoring project works towards the sustainability of engineering activity by developing a tool for research in wildlife conservation.  In addition, the group attended D-School to develop skills in design approaches. PETG was the chosen material based on its durability and its recyclable nature. \\ \hline

    GA8 & Individual, Team, and Multidisciplinary Working & Throughout the project, teamwork was key in making sure the final product was integrated successfully from the individual piece sections. This involved creating a joint literature review, along with communicating weekly on Microsoft Teams. Extensive discussions were conducted, with the main objective of finding the perfect solution to meet the stakeholder requirements, as well as dividing the work into equal subsystems. Thereafter, individual work was conducted to the 3 modular cases capable of housing and meeting the requirements of their environment and components weight. The group members encompassed a multidisciplinary engineering team, with specialisations in Electrical engineering, Electrical and Computer Engineering, and Mechatronics. The project also involved extensive engagement with ornithological researchers, who work outside of the engineering field. \\ \hline

    GA10 & Engineering Professionalism & Throughout the project, professional relationships and communication were maintained with the other group members, project stakeholders and project staff. All submission activities were submitted on time including final report and presentation.  \\ \hline

\end{tabularx}
\raggedright

%------------------------------------------------------------
\ifstandalone
\bibliography{../Bibliography/References.bib}
\printnoidxglossary[type=\acronymtype,nonumberlist]
\fi
\end{document}

%------------------------------------------------------------
\ifstandalone
\bibliography{../Bibliography/References.bib}
\printnoidxglossary[type=\acronymtype,nonumberlist]
\fi
\end{document}

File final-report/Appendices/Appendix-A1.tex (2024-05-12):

\documentclass[class=report,11pt,crop=false]{standalone}
\input{../Style/ChapterStyle.tex}
\input{../FrontMatter/Glossary.tex}
\begin{document}
\ifstandalone
\tableofcontents
\fi
%------------------------------------------------------------

% \appendix{Evidence of GAs met}

\chapter{Additional design information \label{a:A}}

\section{Project Repository}

A number of project resources are available in the \href{https://github.com/rothdu/EEE4113F-Group13-2024}{project repository} on GitHub.

\section{Bill of Materials}

\begin{table}[h]
\centering
\begin{tabular}{|l|l|r|}
\hline
\textbf{Qty.} & \textbf{Component} & \textbf{Price} \\
\hline
2 & MicroSD Card Holder & R46.00 \\
1 & ESP32 CAM & R235.00 \\
1 & Jumper Cables & R23.00 \\
2 & PIR Sensors & R66.40 \\
2 & SD Card & R165.00 \\
1 & 433MHz RF Link Kit & R59.00 \\
1 & LDR & R25.30 \\
1 & Pi Pico W & R134.90 \\
1 & Backlight LCD Display & R66.70 \\
1 & Toggle Switch & R27.60 \\
2 & MOSFET & R8.48 \\
1 & LM358 & R5.69 \\
\hline
\multicolumn{2}{|r|}{\textbf{Total}} & R863.07 \\
\hline
\end{tabular}
\caption{Chapter \ref{ch:hardware} BOM}
\label{tab:HW_BOM}
\end{table}

\begin{table}
\centering

\begin{tabular}{|l |l |l |l |l|} \hline 
Place & Device & Unit Price & Qty & Total price \\ \hline 
 &  &  &  &  \\ \hline 
Communica & Heatsink & R18,00 & 4 & R72 \\ \hline 
Communica & enclosure & R115,00 & 1 & R115 \\ \hline 
Communica & Tubing & R8.63 & 5 & 43,15 \\ \hline 
Digikey & air filter & R30.81 & 2 & R61,62 \\ \hline 
Total &  &  &  & R291.77 \\ \hline

\end{tabular}
\caption{Mechanical BOM }
\label{tab: Mechanical BOM (Online)}
\end{table}

\begin{table}
\centering

\begin{tabular}{|l |l |l |l |l|} \hline 
Place & Device & Unit Price & Qty & Total price \\ \hline 
BUCO & Screws & 30 & 2 & R60 \\ \hline 
BUCO & Silicone Sealant & 51,29 & 1 & R51,29 \\ \hline 
BUCO & VAT & 16, 69 & 1 & R16, 69 \\ \hline 
Total &  &  &  & R127,98 \\ \hline

\end{tabular}
\caption{Mechanical BOM (In-person purchase)}
\label{tab:Mechanical BOM (In-person purchase)}
\end{table}

\begin{table}
\centering

\begin{tabular}{|l |l |l |l |l|} \hline 
Solar Battery Charger &  &  &  &  \\ \hline 
Manufacturer & Part Name & unit price (ZAR) & Qty & Price (ZAR) \\ \hline 
Communica & Voltage Reg & 9,95 & 6 & 59,7 \\ \hline 
Communica & 10K Pot & 10,81 & 5 & 54,05 \\ \hline 
Communica & Zener Diode & 1,32 & 5 & 6,6 \\ \hline 
Communica & Zener Diode & 0,58 & 5 & 2,9 \\ \hline 
Communica & 1/4W 220 ohm & 0,16 & 5 & 0,8 \\ \hline 
Communica & 1/4W 2k ohm & 0,07 & 5 & 0,35 \\ \hline 
Communica & 5W 10 ohm & 2,59 & 5 & 12,95 \\ \hline 
Communica & Multicolour Led & 50 & 1 & 50 \\ \hline 
Communica & Rectifier Diode & 0,44 & 5 & 2,2 \\ \hline 
 &  &  &  &  \\ \hline 
Reverse Polarity &  &  &  & 189,55 \\ \hline 
Manufacturer & Part Name & unit price (ZAR) & Qty & Price (ZAR) \\ \hline 
Mantech & P-Mosfet & 20,61 & 2 & 41,22 \\ \hline 
Communica & Zener diode & 0,58 & 2 & 1,16 \\ \hline 
Mantech & Resistor & 0,25 & 2 & 0,5 \\ \hline 
 &  &  &  & 42,88 \\ \hline 
Battery Level Indicator &  &  &  &  \\ \hline 
Communica & Zener diode & 0,58 & 2 & 1,16 \\ \hline 
Communica & Zener diode & 0,58 & 2 & 1,16 \\ \hline 
Communica & Zener diode & 0,58 & 2 & 1,16 \\ \hline 
Communica & Zener diode & 0,58 & 2 & 1,16 \\ \hline 
 &  &  &  & 4,64 \\ \hline 
Buck Converter &  &  &  &  \\ \hline 
Communica & 555 timer & 2,52 & 3 & 7,56 \\ \hline 
Mantech & Resistor & 0,25 & 3 & 0,75 \\ \hline 
Communica & Zener diode & 0,58 & 3 & 1,74 \\ \hline 
Mantech & MOSFET & 10,62 & 3 & 31,86 \\ \hline 
 &  &  &  & 41,91 \\ \hline 
 &  &  &  &  \\ \hline 
 &  &  &  &  \\ \hline 
Total &  &  &  & 278,98 \\ \hline

\end{tabular}
\caption{Power BOM}
\label{tab:my_table}
\end{table}

Grand Total: R1561.80 (Under Budget)

%------------------------------------------------------------
\ifstandalone
\bibliography{../Bibliography/References.bib}
\printnoidxglossary[type=\acronymtype,nonumberlist]
\fi
\end{document}

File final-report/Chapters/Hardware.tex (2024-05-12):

% ----------------------------------------------------
% Firmware Submodule
% ----------------------------------------------------
\documentclass[class=report,11pt,crop=false]{standalone}
\input{../Style/ChapterStyle.tex}
\input{../FrontMatter/Glossary.tex}
\begin{document}
\ifstandalone
\tableofcontents
\fi
% ----------------------------------------------------
\chapter{Camera/Transmitter (CT) \& Receiver (R) Hardware (PLLTHI032)\label{ch:hardware}}

\section{Subsystem introduction}\label{sc: HW_intro}
This section involves the design and implementation of the hardware for the transmitter/camera and receiver module for a Red-winged Starling nest monitoring system. The focus is to design a camera system that is motion activated when there is activity in the nest. This data is then transferred to a handheld receiver operated by the user on the ground. 

\section{Requirements \& Specifications}\label{sc: HW_R_S}
\begin{table}[h]
\centering
\begin{tabular}{|p{4cm}|p{5cm}|p{5cm}|p{1cm}|}
\hline
\textbf{User Requirements} & \textbf{Functional Requirements} & \textbf{Specifications} & \textbf{ATP} \\
\hline
Clear images of the birds must be captured and stored onboard. & The CT should be capable of capturing and storing quality images in all lighting conditions. & Camera should have infrared light, automated day/night mode switching, and fast onboard storage. & ATP1, ATP2 \\
\hline
The camera should only turn on with motion & The camera should trigger when there is movement. & Equip the CT with PIR sensors for motion detection. & ATP3 \\
\hline
The CT should transmit data wirelessly, avoiding cables & The CT should be capable of wireless data transmission. & The CT must be equipped with a working wireless module. & ATP1, ATP4 \\
\hline
The CT must be as small as possible. & The CT should not be too big as to disturb the birds. & The CT module must be no bigger than 60mm(W) x 80mm(L) x 60mm(H). & ATP5 \\
\hline
The Receiver must have wireless connectivity. & The receiver should be capable of establishing a wireless connection. & The receiver must be equipped with a wireless module. & ATP6 \\
\hline
The receiver must have onboard storage to store the retrieved data. & The receiver should be able to store the data onboard to be used later. & The receiver must have a MicroSD card option for storage. & ATP7 \\
\hline
The receiver must have a screen and interactive buttons to view the basic information. & The receiver should have buttons for easy navigation through the UI. & The receiver must be equipped with a screen and have 4 pushbuttons configure with internal pull up resistors. & ATP8 \\
\hline
\end{tabular}
\caption{User Requirements, Functional Requirements, Specifications, and ATP}
\label{tab:HW_Requirements}
\end{table}

\section{Design Process}\label{sc: HW_DP}

\subsection{Wired vs. Wireless Communication}
There are two options for communication: wired and wireless. the table below goes through the aspects of each. 

\begin{table}[h]
\centering
\begin{tabular}{|p{3.5cm}|p{6cm}|p{6cm}|}
\hline
\textbf{Aspect} & \textbf{Wired Communication} & \textbf{Wireless Communication} \\
\hline
Medium & Physical cables needed. & No physical cables, just radio signals. \\
\hline
Antenna & No need. & Needed for long distance data transfer. \\
\hline
Distance & Better for short distance. & Better for long distance. \\
\hline
Power Consumption & Lower due to cabling. & Higher due to antenna (active components). \\
\hline
Speed & Low latency – ideal for real-time applications. & Suitable for medium to high-speed data transfer. \\
\hline
Mobility & Limited with physical cables. & Free range in coverage area. \\
\hline
Security & Easy to damage physical cables. & Robust security protocols can be used. \\
\hline
Maintenance & High & Low \\
\hline
\end{tabular}
\caption{Comparison of Wired and Wireless Communication}
\label{tab:HW_communication_comparison}
\end{table}

With the nests located high up on buildings, wireless communication offers the user better access despite slightly slower speeds. The disadvantages of using wireless communication does not warrant a change to wired communication. 

\subsection{Wireless Communication Protocols}
There is no shortage of options when it comes to wireless communication protocols. The table below discusses the criterion upon which the different protocols were assessed on. 

\begin{table}[h]
\centering
\begin{tabular}{|p{4cm}|p{12cm}|}
\hline
\textbf{Criteria} & \textbf{Justification (Pass/Fail)} \\
\hline
Range \& Coverage & Can data be transmitted over a range of 10-15 m outdoors with minimal data loss? \\
\hline
Data Rate & Can higher data transfer rates be obtained (higher than 10 Mbps)? \\
\hline
Power Consumption & Is this protocol optimised to work well with low powered battery systems? \\
\hline
Latency & Does the protocol have a latency lower than 100ms? \\
\hline
Interference \& Noise & Is the protocol functional in crowded frequency bands? \\
\hline
Cost & Is this protocol affordable to design and maintain? \\
\hline
Payload & Is the protocol able to handle large data file transmission? \\
\hline
Existing Libraries \& Support & Does the protocol have available libraries and examples to use? Is there reliable developer support? \\
\hline
\end{tabular}
\caption{Criteria for Assessing Wireless Protocols}
\label{tab:HW_Comm_Criteria}
\end{table}

The criteria above will be used to grade each protocol with a pass or fail. The more passes a protocol has, the more likely it was to be chosen. 

\begin{table}[h]
\centering
\begin{tabular}{|l|l|l|l|l|l|l|}
\hline
\textbf{Criteria} & \textbf{BLE} & \textbf{Bluetooth Classic} & \textbf{ESP-Now} & \textbf{Wi-Fi} & \textbf{LoRa} & \textbf{RFID} \\
\hline
Range \& Coverage & \textcolor{red}{Fail} & \textcolor{red}{Fail} & \textcolor{ForestGreen}{Pass} & \textcolor{ForestGreen}{Pass} & \textcolor{ForestGreen}{Pass} & \textcolor{ForestGreen}{Pass} \\
\hline
Data Rate & \textcolor{red}{Fail} & \textcolor{red}{Fail} & \textcolor{red}{Fail} & \textcolor{ForestGreen}{Pass} & \textcolor{red}{Fail} & \textcolor{red}{Fail} \\
\hline
Power Consumption & \textcolor{ForestGreen}{Pass} & \textcolor{red}{Fail} & \textcolor{ForestGreen}{Pass} & \textcolor{red}{Fail} & \textcolor{ForestGreen}{Pass} & \textcolor{ForestGreen}{Pass} \\
\hline
Latency & \textcolor{red}{Fail} & \textcolor{ForestGreen}{Pass} & \textcolor{ForestGreen}{Pass} & \textcolor{ForestGreen}{Pass} & \textcolor{ForestGreen}{Pass} & \textcolor{ForestGreen}{Pass} \\
\hline
Interference \& Noise & \textcolor{ForestGreen}{Pass} & \textcolor{ForestGreen}{Pass} & \textcolor{ForestGreen}{Pass} & \textcolor{ForestGreen}{Pass} & \textcolor{red}{Fail} & \textcolor{red}{Fail} \\
\hline
Cost & \textcolor{ForestGreen}{Pass} & \textcolor{red}{Fail} & \textcolor{ForestGreen}{Pass} & \textcolor{ForestGreen}{Pass} & \textcolor{red}{Fail} & \textcolor{red}{Fail} \\
\hline
Payload & \textcolor{ForestGreen}{Pass} & \textcolor{ForestGreen}{Pass} & \textcolor{red}{Fail} & \textcolor{ForestGreen}{Pass} & \textcolor{red}{Fail} & \textcolor{red}{Fail} \\
\hline
Existing Libraries \& Support & \textcolor{ForestGreen}{Pass} & \textcolor{ForestGreen}{Pass} & \textcolor{ForestGreen}{Pass} & \textcolor{ForestGreen}{Pass} & \textcolor{ForestGreen}{Pass} & \textcolor{ForestGreen}{Pass} \\
\hline
\end{tabular}
\caption{Assessment of Different Wireless Protocols}
\label{tab:HW_Comm_Result}
\end{table}

Both WiFi and ESP-NOW emerged as viable options from this evaluations, with the fewest fails of all the options. Looking at the fails of ESP-NOW, it has an very low payload of around 250 bytes, making it capable of sending only messages between boards. The data rate is around 1 Mbps, which is okay, but not as fast as WiFi. 
WiFi, on the other hand, only has issues with power consumption. With the high speed data transfer and lower latency relative to the other options, this is an acceptable trade off. While yes, there are other options that offer lower power consumption, the data transfer is also slower. Looking at the bigger picture, if the data rate is slower, despite having a lower power consumption, the module will have to stay on for longer till the transfer is complete. This could consume even more power than WiFi, since the module would not have to stay on for that much longer. 
The user also does not want to wait a very long time to retrieve the data. Their time is important. WiFi is chosen. The next part of the design process looks at the different micro-controller options. 

\subsection{Transmitter Microcontroller}

There are millions of different WiFi microcontrollers to choose from in the market, ranging from Arduino, ESP, NRF Dev boards, Raspberry Pi Pico W, and ST Micron Dev boards. However, the NRF boards are extremely expensive, and only offer BLE communication, not to mention minimal customer support. The Arduino board options, like the nano 33 IOT and UNO Wi-Fi, are expensive and bulky respectively. The ST Micro Dev Boards are also quite costly in their own regard, since all the affordable options have been sold out, like the STM32F401, but one would need to look at external Wi-Fi modules since those are sold separately. This leaves the Raspberry Pi Pico W and ESP boards. The table below will lay out a set of criteria that different boards will be assessed on to see which one would be suitable to fulfill the needs of the transmitter.

\begin{table}[h]
\centering
\begin{tabular}{|l|p{10cm}|}
\hline
\textbf{Criteria} & \textbf{Justification} \\
\hline
Processing Power & Does the microcontroller have enough processing power in terms of the number of cores and clock speed (~240 MHz)? \\
\hline
Memory & Is there enough RAM and flash memory to handle tasks related to handling images? \\
\hline
Low Power Modes & Does the microcontroller have low power standby modes available? \\
\hline
Power Consumption & Is the microcontroller power efficient in active mode? \\
\hline
Input/Output (I/O) Pins & Can the microcontroller support external peripherals with available I/O pins? \\
\hline
Development Environment & Are there enough tools available to assist with development? \\
\hline
Cost & Is the microcontroller affordable? \\
\hline
Size & Is the microcontroller small and compact? \\
\hline
\end{tabular}
\label{tab:HW_CT_Criteria_1}
\end{table}

\begin{table}[h]
\centering
\begin{tabular}{|l|p{10cm}|}
\hline
\textbf{Criteria} & \textbf{Justification} \\
\hline
Existing Libraries \& Support & Does the microcontroller have many libraries available and community support? \\
\hline
Operating Voltage & Is the operating voltage of the microcontroller 5V? \\
\hline
Camera Support & Does this microcontroller have good support with regards to camera attachments? \\
\hline
Weight & Does the microcontroller weigh more than 30 g? \\
\hline
MicroSD card holder & Does the microcontroller have a microSD card holder onboard \\
\hline
\end{tabular}
\caption{Criteria for the Transmitter Microcontroller Selection}
\label{tab:HW_CT_Criteria_2}
\end{table}

The table below proceeds to assess four potential board which have been chosen for the transmitter submodule against the criterion outlines in Table \ref{tab:HW_CT_Criteria_2}.

\begin{table}[h]
\centering
\begin{tabular}{|p{3.5cm}|l|l|l|l|l|}
\hline
\textbf{Criteria} & \textbf{Pi Pico W} & \textbf{ESP32-CAM} & \textbf{ESP32-CH340} & \textbf{ESP32-C6} & \textbf{ESP32 S3} \\
\hline
Processing Power & \textcolor{red}{Fail} & \textcolor{ForestGreen}{Pass} & \textcolor{ForestGreen}{Pass} & \textcolor{red}{Fail} & \textcolor{ForestGreen}{Pass} \\
\hline
Memory & \textcolor{ForestGreen}{Pass} & \textcolor{ForestGreen}{Pass} & \textcolor{ForestGreen}{Pass} & \textcolor{ForestGreen}{Pass} & \textcolor{ForestGreen}{Pass} \\
\hline
Low Power Modes & \textcolor{ForestGreen}{Pass} & \textcolor{ForestGreen}{Pass} & \textcolor{ForestGreen}{Pass} & \textcolor{ForestGreen}{Pass} & \textcolor{ForestGreen}{Pass} \\
\hline
Power Consumption & \textcolor{ForestGreen}{Pass} & \textcolor{ForestGreen}{Pass} & \textcolor{red}{Fail} & \textcolor{ForestGreen}{Pass} & \textcolor{red}{Fail} \\
\hline
Input/Output (I/O) Pins & \textcolor{ForestGreen}{Pass} & \textcolor{red}{Fail} & \textcolor{ForestGreen}{Pass} & \textcolor{ForestGreen}{Pass} & \textcolor{ForestGreen}{Pass} \\
\hline
Development Environment & \textcolor{ForestGreen}{Pass} & \textcolor{ForestGreen}{Pass} & \textcolor{ForestGreen}{Pass} & \textcolor{ForestGreen}{Pass} & \textcolor{ForestGreen}{Pass} \\
\hline
Cost & \textcolor{ForestGreen}{Pass} & \textcolor{ForestGreen}{Pass} & \textcolor{ForestGreen}{Pass} & \textcolor{red}{Fail} & \textcolor{ForestGreen}{Pass} \\
\hline
Size & \textcolor{ForestGreen}{Pass} & \textcolor{ForestGreen}{Pass} & \textcolor{red}{Fail} & \textcolor{red}{Fail} & \textcolor{ForestGreen}{Pass} \\
\hline
Existing Libraries \& Support & \textcolor{ForestGreen}{Pass} & \textcolor{ForestGreen}{Pass} & \textcolor{ForestGreen}{Pass} & \textcolor{ForestGreen}{Pass} & \textcolor{ForestGreen}{Pass} \\
\hline
Operating Voltage & \textcolor{ForestGreen}{Pass} & \textcolor{ForestGreen}{Pass} & \textcolor{ForestGreen}{Pass} & \textcolor{ForestGreen}{Pass} & \textcolor{ForestGreen}{Pass} \\
\hline
Camera Support & \textcolor{ForestGreen}{Pass} & \textcolor{ForestGreen}{Pass} & \textcolor{ForestGreen}{Pass} & \textcolor{red}{Fail} & \textcolor{red}{Fail} \\
\hline
Weight & \textcolor{ForestGreen}{Pass} & \textcolor{ForestGreen}{Pass} & \textcolor{ForestGreen}{Pass} & \textcolor{ForestGreen}{Pass} & \textcolor{ForestGreen}{Pass} \\
\hline
MicroSD card holder & \textcolor{red}{Fail} & \textcolor{ForestGreen}{Pass} & \textcolor{red}{Fail} & \textcolor{red}{Fail} & \textcolor{red}{Fail} \\
\hline
\end{tabular}
\caption{Assessment of Different Transmitter Microcontrollers}
\label{tab:HW_CT_Result}
\end{table}

The Pi Pico W and ESP32-CH340 have poor processing power and power consumption respectively, with the latter having an additional space constraint. The ESP32-C8 had similar limitations, while also being expensive with poor camera support. The ESP32 S3 lacks camera support and has bad power consumption. 

The ESP32-CAM stands out, offering an onboard MicroSD card holder with quad SPI and camera, with support for external antenna. While there are fewer GPIO pins available for external devices, the trade-offs with the other boards are far worse, since the other options would need an external camera and MicroSD card. This would increase power consumption, cost and reduces the GPIO pins available. The ESP32-CAM avoids these issues, which is why it was chosen. 

\subsection{Receiver Microcontroller}

Table \ref{tab:HW_Requirements} detailed what the Receiver module should have. The table below lays out a set of criteria to assess different microcontroller options. However, since the microcontroller options have already been assessed in the previous section, just a few of the amended criteria will be looked at. 

\begin{table}[h]
\centering
\begin{tabular}{|l|p{10cm}|}
\hline
\textbf{Criteria} & \textbf{Justification} \\
\hline
Processing Power & Does the microcontroller have enough processing power in terms of the number of cores and clock speed (~100 MHz)? \\
\hline
Memory & Is there enough RAM and flash memory to handle image transfer? \\
\hline
Input/Output (I/O) Pins & Are there enough GPIO pins on the microcontroller to support a screen (I2C) and MicroSD card (SPI)? \\
\hline
Cost & Is the microcontroller affordable? \\
\hline
Size & Is the microcontroller small and compact? \\
\hline
Weight & Does the microcontroller weigh more than 5 g? \\
\hline
\end{tabular}
\caption{Criteria for Receiver Microcontroller Selection}
\label{tab:HW_R_Criteria}
\end{table}

Using table \ref{tab:HW_R_Criteria}, three microcontrollers from table \ref{tab:HW_CT_Criteria_2} are assessed to see if they meet the demands of this module.

\begin{table}[h]
\centering
\begin{tabular}{|l|l|l|l|}
\hline
\textbf{Criteria} & \textbf{Pi Pico W} & \textbf{ESP32-C6} & \textbf{ESP32 S3} \\
\hline
Processing Power & \textcolor{ForestGreen}{Pass} & \textcolor{ForestGreen}{Pass} & \textcolor{ForestGreen}{Pass} \\
\hline
Memory & \textcolor{ForestGreen}{Pass} & \textcolor{ForestGreen}{Pass} & \textcolor{ForestGreen}{Pass} \\
\hline
Input/Output (I/O) Pins & \textcolor{ForestGreen}{Pass} & \textcolor{ForestGreen}{Pass} & \textcolor{ForestGreen}{Pass} \\
\hline
Cost & \textcolor{ForestGreen}{Pass} & \textcolor{red}{Fail} & \textcolor{ForestGreen}{Pass} \\
\hline
Size & \textcolor{ForestGreen}{Pass} & \textcolor{red}{Fail} & \textcolor{ForestGreen}{Pass} \\
\hline
Weight & \textcolor{ForestGreen}{Pass} & \textcolor{red}{Fail} & \textcolor{red}{Fail} \\
\hline
\end{tabular}
\caption{Assessment of Different Receiver Microcontrollers}
\label{tab:HW_R_Result}
\end{table}

This was an easy decision. The Pi Pico W was the smallest, cheapest, and lightest microcontroller option. It had the best price to performance ratio, hence why it is chosen to operate the receiver module. 

\subsection{Miscellaneous Parts}
\begin{itemize}
    \item PIR Sensors: It would be power inefficient if the ESP32 CAM were on all the time. To solve this, the Mini PIR Sensor (HC-SR505) was picked since it had a 100 degree detection angle, and low quiescent current (low power consumption). The transmitter module will be equipped with two of these. An OR gate will combine their output that is sent to the microcontroller to reduce the GPIO pins used. details on that circuit in the design section. 
    \item Infrared Lights: This is needed for the images captured at night to be visible. There are two different wavelengths to choose from; 850 nm and 940 nm. While 850nm deliver exceptional images in lowlight conditions but gives off a bright red glow when on. 940 nm is a more viable option if minimal invasion is required, i.e., the requirements of this product. Despite delivering lower image quality, there is no visible light that may disturb the birds. Therefore, 940 nm IR LEDs were picked for this product. It might be difficult to test if a 940 nm IR LED works since this light is beyond the visible spectrum. Just make sure the voltage drop is 1.1 V and the current draw is around 50 mA. 
    \item 433MHz RF Link Kit: When the transmitter is in sleep mode, the WiFi module is inactive, so the receiver will not be able to establish a WiFi connection. This component has its own receiver and transmitter. The receiver pulls the GPIO pin that the RF transmitter is connected to high when there is no connection. This pings the RF receiver, which is connected to a pin on the transmitter. Both RF transmitter and receiver are powered with 5V. The data pins (connected to the microcontrollers) output a 3V3 signal when high and 0V when low. 
    \item MicroSD card (SPI): This is needed for the receiver since the Pi Pico W does not have a built-in MicroSD card. The microcontroller only supports normal SPI, not quad SPI like the ESP32-CAM. A simple module with 6 pins: (1)VCC, (2)GND, (3)CS, (4)CLK, (5)MOSI, and (6)MISO was purchased. The module needs 3V3 power. 
    \item Display (I2C): The information the user needs can be shown on a 16x2 liquid crystal display. Four pushbuttons are used to interact with the display. Each button is configured with an internal pull-up resistor. The screen connects to the Pi using I2C, and is powered by 3V3. 
\end{itemize}

\section{Final Design}\label{sc: HW_FD}

\subsection{General Overview}
\begin{figure}[h]
\centering
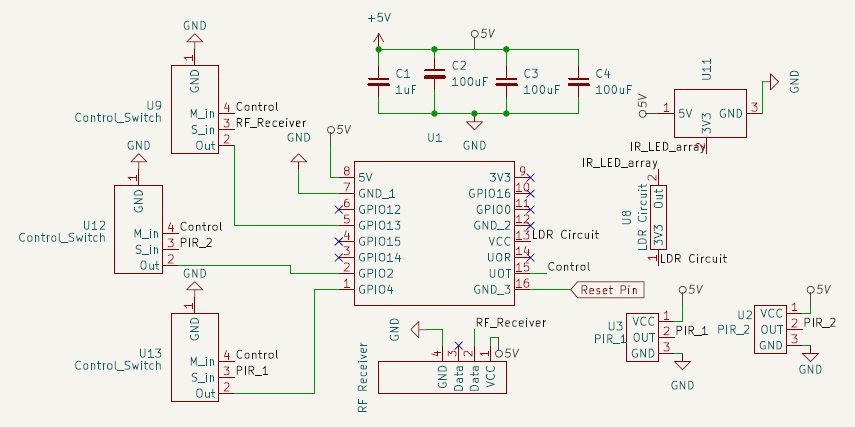
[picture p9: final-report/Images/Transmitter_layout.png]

\caption{Final Transmitter Board Layout}
\label{fig:T_Schem}
\end{figure}

In the transmitter, shown in Figure \ref{fig:T_Schem}, the ESP32-CAM, powered by 5VDC. is the main hub that houses the connections for the LDR circuit, IR LED array, PIR sensors, and RF receiver. 
Given the limited GPIO pins, which become unusable when the WiFi module or MicroSD card are active, the PIR sensors and RF receiver are connected to Real-Time Clock (RTC) pins. These are the only pins that wake up the ESP32-CAM from deep sleep. 

When either of the two PIR sensors detect motion, the ESP32-CAM is activated (through PNP switches), which turns on the LDR circuit (through the VCC pin); if it is dark, the IR LED circuit turns on to light up the area. GPIO1, which is fed to the base of the PNP switch, would go high as soon as the ESP32-CAM is activated, to prevent the board from shorting the sensors. The OV2640 camera is a 2MP camera with a maximum resolution of 1280x720. The IR filter present in the lens was challenging to remove. 

When the RF Receiver goes high from the user sending a signal from the RF transmitter, the ESP32-CAM is activated for data transmission. The same PNP switch as used for the PIR connections was used here. 

The storage is limited to 4GB. The HC MicroSD card must be formatted to FAT32. The RF receiver wakes the ESP32-CAM out of deep sleep mode for data retrieval (since WiFi also becomes inactive). 

\begin{figure}[h]
\centering
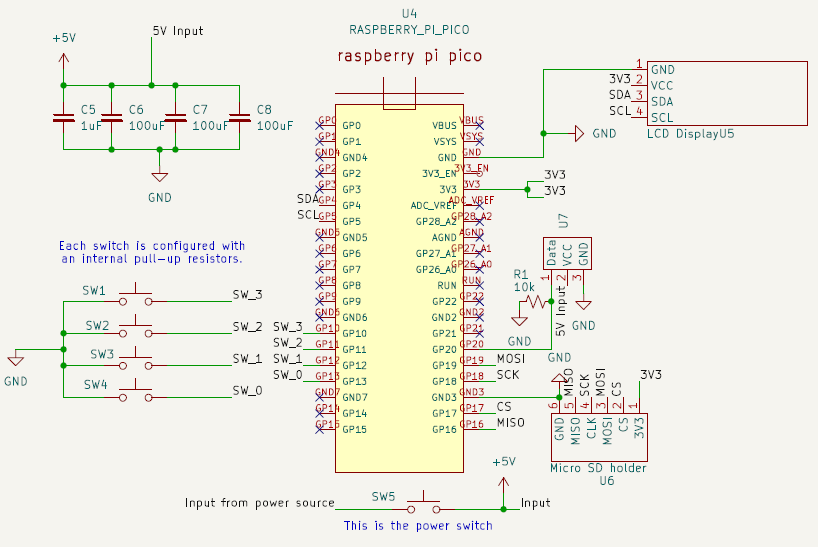
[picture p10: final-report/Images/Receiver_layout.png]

\caption{Final Receiver Board Layout}
\label{fig:R_Schem}
\end{figure}

In the receiver, shown in Figure \ref{fig:R_Schem}, the Pi Pico W is the main hub connecting various peripherals:
\begin{itemize}
    \item Liquid Crystal Display: The module connects to the Pi Pico W with I2C protocol. The GPIO4 and GPIO5 pins are connected to SDA and SCL respectively. The 3V3 pin and GND pins are connected to the VCC and Ground pins of the display. 
    \item SD Card Reader: The module connects to the Pi Pico W with SPI protocol. 
    \item Pushbuttons: Allow for the user to interface with the display. These buttons are connected to GPIO10-13. 
    \item RF Transmitter: The data line connects to GPIO20 on the Pi Pico W. When the WiFi connection cannot be established between the Pi Pico W and the ESP32-CAM, then GPIO20 is set high to activate the ESP32-CAM on remotely. 
\end{itemize}

\subsection{Transmitter Support Circuitry and Testing}

\begin{figure}[hbt!]
    \begin{subfigure}[b]{0.25\textwidth}
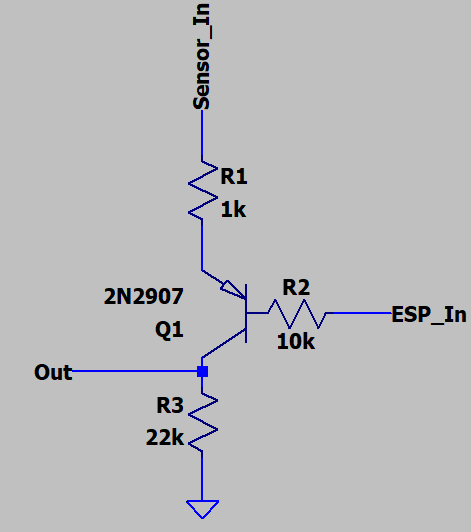
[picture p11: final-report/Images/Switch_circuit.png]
        
        \caption{PNP Switch Schematic}
        \label{fig:PNP_Switch}
    \end{subfigure}
    \hfill
    \begin{subfigure}[b]{0.4\textwidth}
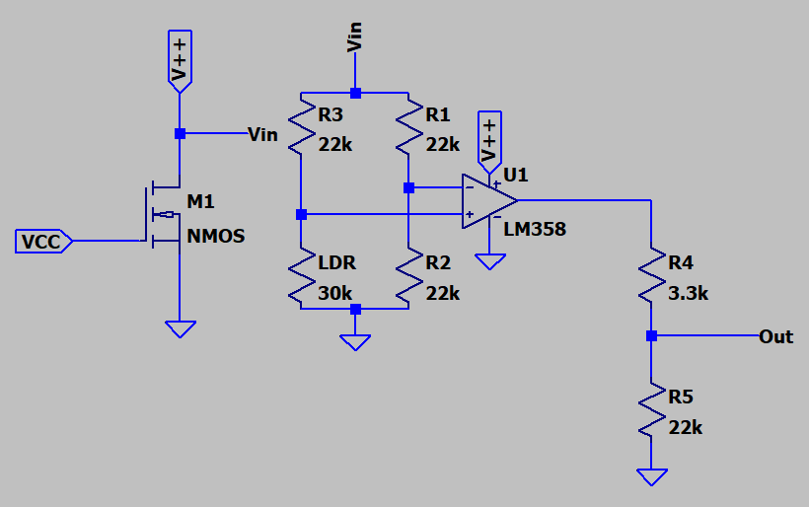
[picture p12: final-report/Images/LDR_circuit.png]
        
        \caption{LDR Comparator Circuit Schematic}
        \label{fig:LDR_schem}
    \end{subfigure}
    \hfill
    \begin{subfigure}[b]{0.25\textwidth}
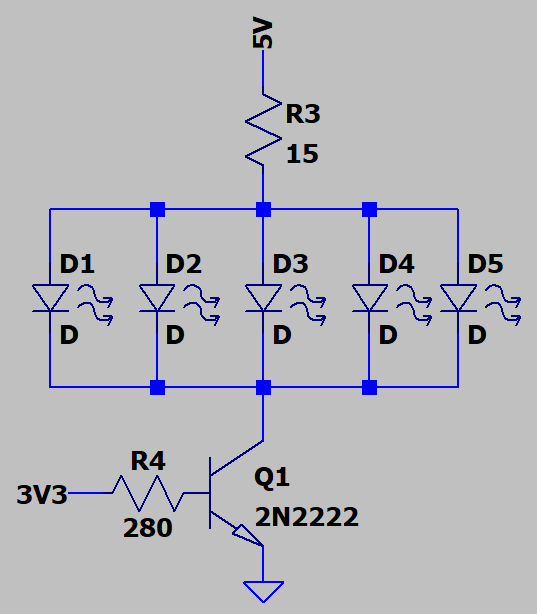
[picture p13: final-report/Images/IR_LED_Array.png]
        
        \caption{IR LED Array Schematic}
        \label{fig:LED_schem}
    \end{subfigure}
\end{figure}

Figure \ref{fig:PNP_Switch} shows a 2N2907 transistor acting as a buffer between the sensor and GPIO pins. A resistor is placed between the Sensor and the emitter to prevent current overload. The collector is connected to the GPIO pin with a resistor pulling the pin to GND. The base is connected to GPIO16 through a 10k resistor. 

When GPIO16 is low, the sensor input is allowed to trigger the GPIO pin. When the sensor input is high, the ESP32-CAM is woken up from deep sleep, and GPIO16 is immediately set to high, to isolate the sensor from the GPIO pin. 

The simulated output was around 3V, which was confirmed in testing when a simulated 3V3 input was applied to the switch, and the base was controlled by a 3V3 voltage. The GPIO pin will still trigger a high since the quoted GPIO range on the ESP datasheet is 2.3V to 3.6V. 

Figure \ref{fig:LDR_schem} shows a basic comparator circuit. The Light Dependent Resistor (LDR) was test under dark conditions, having a resistance of 25k, which dropped in light conditions to 6.5k. The inverting (-) and non-inverting (+) pins are connected to voltage dividers. The (-) pin is connected to 2.5V. The (+) pin is connected to a voltage divider with the LDR. When the surroundings get darker, the resistance increases and the voltage at the (+) increases. Once (V+)>(V-), the output, fed through another voltage divider, will be 3V3. Otherwise the output will be around 0V (22 mV). 

An N-Channel MOSFET is used as a level shift, such that when the 3V3 voltage from the ESP32-CAM is applied to it, the rest of the circuit can then be supplied with 5V, otherwise the circuit is inactive.

Figure \ref{fig:LED_schem} shows a 2N2222 transistor acts as a switch to control the flow of current to 5 IR LEDs are placed in parallel. The switch is operated by the comparator output, i.e., the output from the LDR circuit. When the base is high (3V3), current flows through the LEDs, otherwise, the switch will be off and no current will flow. 

The datasheet quoted that each 950nm LED required 1.1V and 50mA. The circuit was simulated and built to deliver each LED with rated power. Lab testing confirmed that each LED drew 48mA. The emitting light from these LEDs are invisible to the human eye. Normal green LEDs were used to test if the switch was working. The resistor values were adjusted to ensure the rated current was applied to each LED. The circuit functioned perfectly. 

The IR LEDs and corresponding resistors were placed in the circuit and run for 10 minutes with the rated power. The current and voltage remained stable, with the current and voltage across the IR LEDs remaining constant. There was heat being radiated off each LED, which was normal. 

\section{Power Consumption}\label{sc: HW_PC}
\subsection{Transmitter Power Consumption}
Now that the supporting circuits have been constructed, it is time to do an evaluation of the power consumption of the transmitter when the ESP32-CAM is in deep sleep and active mode. 

\begin{table}[h]
\centering
\begin{tabular}{|p{2.5cm}|p{6.5cm}|p{6.5cm}|}
\hline
\textbf{Device} & \textbf{Power Consumption in Deep Sleep} & \textbf{Power Consumption in Active Mode} \\
\hline
ESP32-CAM & 6 mA @ 5 V & 180 mA @ 5 V \\
\hline
PNP Switch & 0 mA @ 0 V & When Sensor input goes high: 0.133 mA @ 5 V \\
& & When base current is applied: 3.31 pA @ 5V \\
\hline
RF Receiver & When output low: 4 mA @ 5 V & When output low: 4 mA @ 5 V \\
& When output high: 20 mA @ 5 V & When output high: 20 mA @ 3.4 V \\
\hline
PIR (x2) & 0.06 mA @ 5 V & 0.06 mA @ 5 V \\
\hline
LDR Circuit & 0 mA @ 0 V & When light: 0.34 mA @ 5V \\
& & When dark: 0.6 mA @ 5V \\
\hline
IR LED Array & 0 mA @ 5 V & When LDR out low: 0 mA @ 5 V \\
& & When LDR out high: 262 mA @ 5 V \\
\hline
Total & Min: 10.06 mA @ 5 V, 50.3 mW & Min: 184.40 mA @ 5 V, 922 mW \\
& Max: 26.06 mA @ 5 V, 130.3 mW & Max: 462.53 mA @ 5 V, 2.31 W \\
\hline
\end{tabular}
\caption{Transmitter Power Consumption}
\label{tab:CT_PWR}
\end{table}

The power consumption reaches a high of 2.31 W when the camera, WiFi and SD card is in use. This should be avoided as much as possible to increase the longevity of the battery onboard. In standby mode, the system performs great by consuming very little power which will help save battery in periods when there is no nest activity. 

\subsection{Receiver Power Consumption}
The receiver will always remain in the active mode. When the user no longer needs to use the Receiver, they can just turn it off. 

\begin{table}[h]
\centering
\begin{tabular}{|l|l|}
\hline
\textbf{Device} & \textbf{Power Consumption in Active Mode} \\
\hline
Pi Pico W & 60 mA @ 5 V \\
\hline
LCD Display & 30 mA @ 3V3 \\
\hline
RF Transmitter & When on standby: 0 mA @ 5 V \\
& When in use: 4 mA @ 5 V \\
\hline
MicroSD Card Holder & 16 mA @ 3V3 \\
\hline
Total & Min: 106 mA @ 5 V, 530 mW \\
& Max: 110 mA @ 5 V, 550 mW \\
\hline
\end{tabular}
\caption{Receiver Power Consumption}
\label{tab:R_PWR}
\end{table}

Power consumption is fairly consistent. These values were calculated when the WiFi module was in operation, so this is possibly the highest power consumption that could be seen on the receiver. 

\section{Testing and Results} \label{sc: HW_TR}
\subsection{Acceptance Test Procedures}

\begin{table}[h]
\centering
\begin{tabular}{|p{1cm}|p{15cm}|}
\hline
\textbf{Code} & \textbf{Description} \\
\hline
ATP1 & Test that the camera can take clear images and store it onboard.\\
\hline
ATP2 & Test the night vision capabilities of the camera module. \\
\hline
ATP3 & Test that the ESP32-CAM wakes up from deep sleep when the PIR picks up motion. \\ 
\hline
ATP4 & Test that the RF receiver pulls the pin on the ESP32-CAM it is connected to high when the RF transmitter is fed a pulse.\\ 
\hline
ATP5 & Test that the CT module can fit in the space constraint. \\
\hline
ATP6 & Initialise a Wi-Fi hotspot on the Pi Pico W to test the module. \\ 
\hline
ATP7 & Test the MicroSD card module.\\ 
\hline
ATP8 & Test if the screen can display text. \\ 
\hline
\end{tabular}
\caption{Table of ATP Descriptions}
\label{tab:ATPs_Criteria}
\end{table}

Below are all the test scripts that will be used in the ATPs. These can be found in the GitHub under "Sample Code":

"ATP1.ino": Create a WiFi hotspot with ssid "ESP\_WiFi" and password "Thiyashan" on your device. Go to Tools>Serial Monitor to get the IP address of the board and input this to the browser on your device. The HTTP server should display with three buttons: ROTATE, CAPTURE PHOTO and REFRESH PAGE, as shown in \ref{fig:ATP1_Test}. Press CAPTURE PHOTO which saves the image to the SD card. Wait 5 seconds then press REFRESH PAGE. If the image displays, then the test passed. Once the test is completed, close application. \cite{randomnerdtutorialsESP32CAMTake}

\begin{figure}[h]
\centering
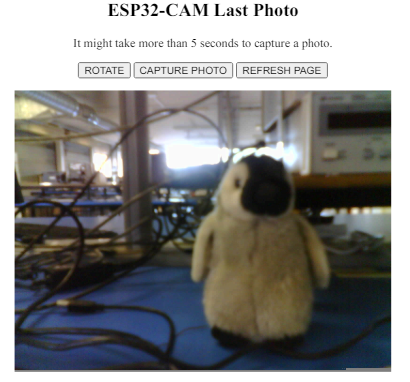
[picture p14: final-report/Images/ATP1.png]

\caption{HTTP Web Page Layout With Image Displayed}
\label{fig:ATP1_Test}
\end{figure}

"ATP6.ino": Once the program is loaded onto the Pi Pico W, open Tools>Serial Monitor and change the baud rate to 115200. Open the WiFi setting on your device, and wait around 10s for "Pi\_WiFi" to appear. Enter password "Thiyashan" if you wish to connect. If the network appears, the it is a pass. Close all applications after test.

"ATP7.ino": The MISO, MOSI, SC, and SCK pins are connected to 16, 19, 17, 18 respectively and initialised as such in the code. Place an SD card with no files into the holder. Run program. This should load a text file called "example.txt". Unplug the SD card and read it on your computer to make sure the text file was generated. If it is there, then the system has passed the ATP. 

"ATP8.ino": Wait around 5 seconds for the message "Hello World" to be displayed on the screen. If this happens, then the screen passes the ATP. 

There are three possible results in table \ref{tab:ATPs_result}. Either a Pass, Fail or Time. Pass and Fail is with regards to the designs ability to satisfy a user requirement. Time means that there was not enough time to fully test the ATP, so the design could pass the ATP if there was sufficient time. 

\begin{table}[h]
\centering
\begin{tabular}{|p{1cm}|p{13cm}|p{2cm}|}
\hline
\textbf{Code} & \textbf{Acceptance Criterion} & \textbf{Result} \\
\hline
ATP1 & The pictures that are taken should be clear at 1m. Load test script "ATP1.ino" and follow the instructions above. & Pass \\
\hline
ATP2 & Place the camera in a dark area to test camera quality. Load test script "ATP1.ino" onto the ESP32-CAM to view the images. & Time* \\
\hline
ATP3 & The PIR must output 3V3 to the GPIO pin it is connected to. When motion stops, it should take around 10s for the voltage to return to zero. The components passes if this happens & Pass \\ 
\hline
ATP4 & When a 3V3 pulse is fed to the RF transmitter, the oscilloscope, set to trigger a rising edge, must detect a 3V3 pulse on the RF receiver. The component passes if this happens & Pass \\ 
\hline
ATP5 & An 60mm(W) x 80mm(L) x 60mm(H) box was constructed out of paper to see if the module fits in the space. If all components fit then it is a pass. & Pass \\
\hline
ATP6 & Load test script "ATP6.ino" onto the Pi Pico W. Once loaded, follow the instructions below the table. & Pass \\ 
\hline
ATP7 & Follow the instruction in "ATP7.ino". & Pass \\ 
\hline
ATP8 & Load test script "ATP8.ino" onto the Pi Pico W and follow the instructions above. & Pass \\ 
\hline
\end{tabular}
\caption{Table of ATP results}
\label{tab:ATPs_result}
\end{table}

* ATP2 failed on time. When purchasing the ESP32-CAM, it was expected that the IR filter was easily removable by opening the lens and popping it out. However, position was relocated in this model to the base of the camera. Accessing it required fully disassembling and desoldering the camera with the risk of permanent damage. With more time this could be completed, or alternatively an older camera model could be purchased but there were not any available that could be purchased before the deadline. 

\section{Conclusion} \label{sc: HW_C}
This subsection was successful in designing a working receiver and camera/transmitter module for the Red Winged Starling nest monitoring system. The design process was thorough, where each decision was graded in 
a pass/fail system to assess whether it was a viable option or not. 

The ESP32-CAM and Pi Pico W were the main hub for the receiver and transmitter in the final design respectively, since each showcased a balance between cost and performance in the grading system. 

The system was built with motion-activated capture and wireless data transfer in mind, while also prioritising power efficiency and cost. The hardware was tested to ensure all components met a set of criteria. Despite the limitations, the design was efficient in the end. 

The design provided insights into the trade-offs that need to be made in order to cater for the specific user needs, as well as future improvements that could be made, such as adding video capabilities and mending the night vision abilities. 

% ----------------------------------------------------
\ifstandalone
\bibliography{../Bibliography/References.bib}
\printnoidxglossary[type=\acronymtype,nonumberlist]
\fi
\end{document}
% ----------------------------------------------------

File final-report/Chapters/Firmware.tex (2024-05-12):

% ----------------------------------------------------
% Firmware Submodule
% ----------------------------------------------------
\documentclass[class=report,11pt,crop=false]{standalone}
\input{../Style/ChapterStyle.tex}
\input{../FrontMatter/Glossary.tex}
\begin{document}
\ifstandalone
\tableofcontents
\fi
\chapter{Firmware (DGMROB001) \label{ch:firmware}}
\section{Subsystem introduction}

This subsystem deals with the development of firmware for the microcontrollers in both the camera/transmitter and receiver modules. The fundamental goals of this subsystem were to enable the camera/transmitter module to take photographs of the red-winged starlings, and to transmit this photographs to the receiver module without disturbing the birds' nests. The source code for this subsystem is available in the \href{https://github.com/rothdu/EEE4113F-Group13-2024}{project repository} on GitHub.

Section \ref{s:firmware-requirements} presents the subsystem's user requirements, interpretted functional requirements, and the corresponding system specifications. Section \ref{s:firmware-design-decisions} discusses high-level design decisions that informed the subsystem development process. Section \ref{s:firmware-design-process} details the design process and the functionality of the final implementation. Finally, section \ref{s:firmware-atps} shows the acceptance test procedures, proving that the user requirements have been adequately met.

The system provided from the hardware subsystem includes an ESP32-Cam for the camera/transmitter module, and a Raspberry Pi Pico W for the receiver. The ESP32-Cam module includes an onboard SD card reader and camera, and integrated WiFi. Externally, it is connected to PIR movement sensors, and an RF receiver (for remote waking from the receiver device). The PIR sensors and RF receiver utilise the same pins as the SD card; the external peripherals must thus be disabled (via a switch connected to a GPIO pin) before the SD card can be initialised. The receiver module includes onboard WiFi. Externally, it is connected to a 16x2 I2C LCD, an SPI SD card reader, and and four pushbuttons for user input.
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

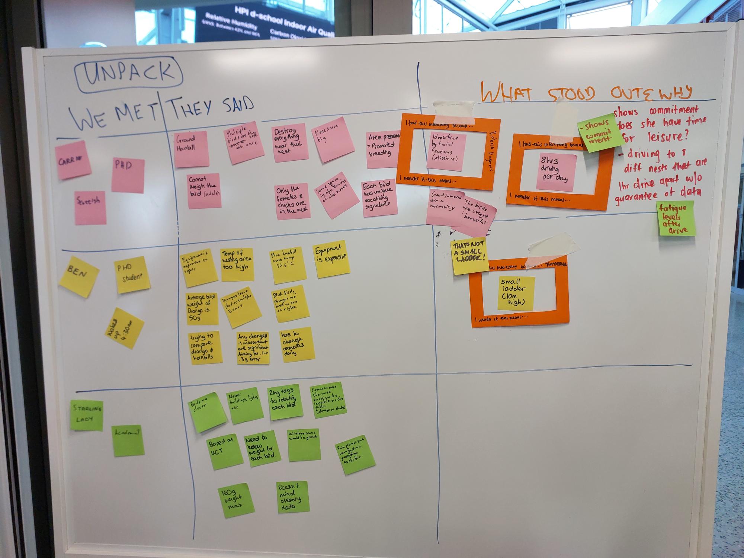
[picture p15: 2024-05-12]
final-report/Images/unpack.jpeg

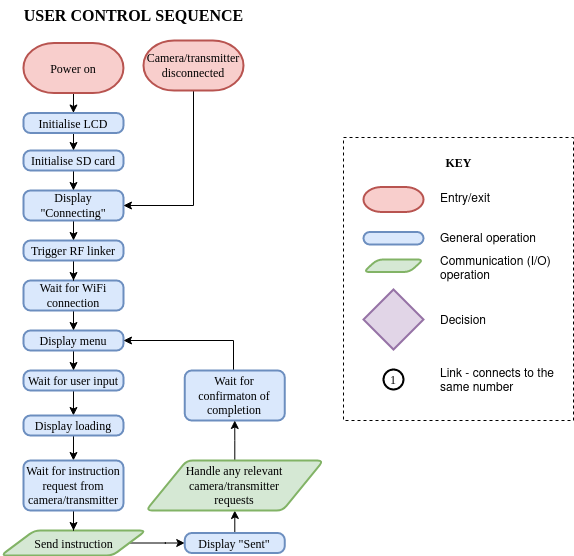
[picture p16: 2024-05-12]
final-report/Images/Pi-flow.png

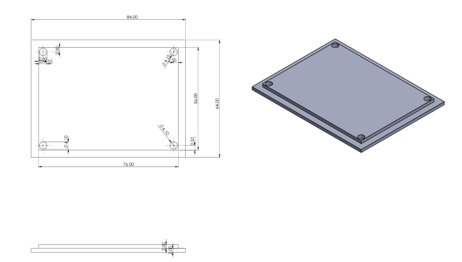
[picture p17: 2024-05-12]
final-report/Images/lid.png

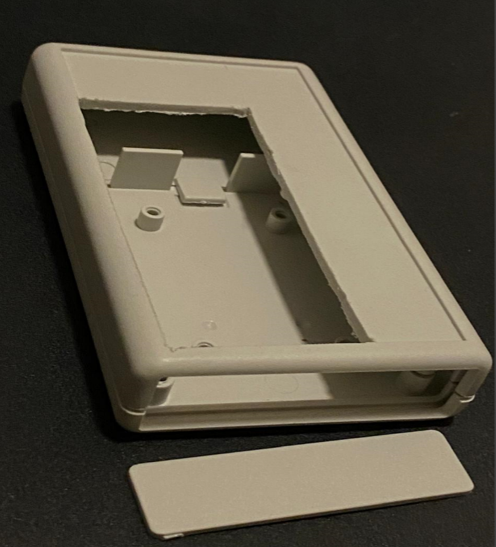
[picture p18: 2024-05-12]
final-report/Images/receiver_house.png

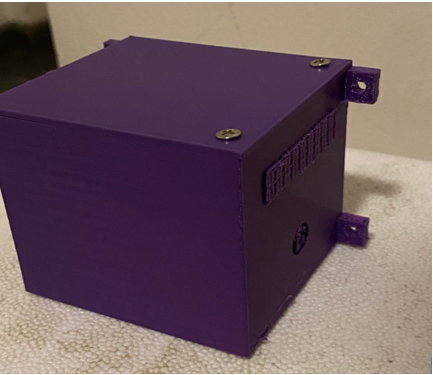
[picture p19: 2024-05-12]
final-report/Images/power_house.png

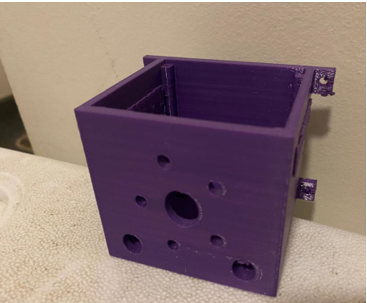
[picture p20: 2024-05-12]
final-report/Images/sensor_house.png

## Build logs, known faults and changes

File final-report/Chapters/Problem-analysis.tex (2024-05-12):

% ----------------------------------------------------
% Introduction
% ----------------------------------------------------
\documentclass[class=report,11pt,crop=false]{standalone}
\input{../Style/ChapterStyle.tex}
\input{../FrontMatter/Glossary.tex}
\begin{document}
\chapter{Problem Analysis \label{ch:problem-analysis}}
% ----------------------------------------------------

\section{D-school activities}
Two afternoon sessions were spent at the Hasso Plattner School of Design Thinking Afrika. In collaboration with instructors from the D-School, the group engaged in various activities aimed at teaching design thinking and understanding the needs of the stakeholders for wildlife conservation projects. The stakeholders presented the challenges they were facing with their research. The group analysed these conversations to gain a deeper understanding of the stakeholders' needs.  

Many of the stakeholders required surveillance of the various birds they were researching. Ultimately the group was drawn towards the project involving nest monitoring for Red-Winged Starlings. The stakeholders appeared to be limited by their tools (a GoPro camera on a stick) \cite{hofmeyer2024private}. The group felt that there was potential to develop a viable product to help with their research. Ultimately, this led to the problem statement:

\begin{quote}
    Sally, an academic researching starlings on UCT campus, requires remote visual surveillance of the birds for an extended period of time without human intervention and without risk of damage or theft of hardware.
\end{quote}

\section{Subsystem breakdown}

This problem was broken down into four subsystems:

\centering
\begin{tabularx}{\textwidth}[]{|p{0.2\textwidth}| X|}
    \hline
    \textbf{Subsystem} & \textbf{Description} \\ \hline
    Power & Deals with power supply. Provides power to the electronic hardware subsystem. \\ \hline
    Electronic hardware & Deals with the design of microcontroller and sensing hardware.\\ \hline
    Firmware & Deals with the firmware development of the microcontrollers, including communications and user interface design. \\ \hline
    Mechanical & Deals with the physical housing of the power and electronic hardware subsystems. \\ \hline
    
\end{tabularx}
\raggedright

% ----------------------------------------------------
\ifstandalone
\bibliography{../Bibliography/References.bib}
\printnoidxglossary[type=\acronymtype,nonumberlist]
\fi
\end{document}
% ----------------------------------------------------

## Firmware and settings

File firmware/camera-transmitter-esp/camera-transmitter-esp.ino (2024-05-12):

// define this to enable debug output on Serial
// #define DEBUG

// define this to run the unit test code rather than the production code
// #define UNIT_TESTS

// define this for ATP1
// #define ATP1

// define this for ATP7
// #define ATP7

#if defined(ATP1) || defined(ATP7)
#define ATPS
#endif
/* MAIN TASKS */
typedef enum{
  SEND_METADATA = 0,
  UPDATE_CONFIG = 1,
  SEND_PHOTOS = 2, 
  SAMPLE_PHOTO = 3,
  EXIT = 4,
  WAIT = 5
  // room to add more if necessary
} t_instruction;
t_instruction currentInstruction = WAIT;
void triggerCapture();
void triggerTransmitter();
void handleInstruction(t_instruction instruction);

/** LIBRARY INCLUDES **/
//Base library
#include <Arduino.h>
// Wifi libraries
#include <WiFi.h>
#include <HTTPClient.h>
// Camera libraries
#include "esp_camera.h"
#include "soc/soc.h"
#include "soc/rtc_cntl_reg.h"
#include "driver/rtc_io.h"
// MicroSD Libraries
#include "FS.h"
#include "SD_MMC.h"
#include <ArduinoJson.h>
 
// Counter for picture number
unsigned int pictureCount = 0;

/* SD CARD */
String configDir = "/config";
String numPhotosPath = "/config/numPhotos.json";
String newNumPhotosJson = "{\"numPhotos\":0}";
/* sd-control.ino prototypes */
bool initMicroSDCard();
bool setNumPhotos(uint32_t numPhotos);
uint32_t getNumPhotos();
bool deleteAndRecreateNumPhotos();
bool checkAndCreateDir(String dirPath);


/* CONFIG FILE */
String configFilePath = "/config/config.json";
/* config-file-init.ino prototypes */
bool loadFromConfig();
bool networkConfig(JsonObject networkObj);
bool cameraConfig(JsonObject cameraObj);
bool cameraTimingConfig(JsonObject cameraTimingObj);

/* NETWORK */
String ssid = "starling-hub";
String password = "ilovestarlings";
String serverAddress = "http://192.168.42.1:8080"; // server IP, can up updated via config
WiFiClient client; // client for reading stream from server
HTTPClient http;
const uint8_t numAttempts = 3; // global number of attempts at a web request before giving up and going back to sleep
uint8_t numWiFiFails = 0;
/* web-requests.ino prototypes */
int16_t sendPhoto(String thisPhotoDir, String thisPhotoName, uint32_t photoNum);
uint32_t sendAllPhotos();
int16_t updateConfig();
int16_t requestInstruction();
bool initWiFi();
void onWiFiEvent(WiFiEvent_t event);

/* CAM */
// pin definitions for AI Thinker ESP-CAM
#define PWDN_GPIO_NUM     32
#define RESET_GPIO_NUM    -1
#define XCLK_GPIO_NUM      0
#define SIOD_GPIO_NUM     26
#define SIOC_GPIO_NUM     27
#define Y9_GPIO_NUM       35
#define Y8_GPIO_NUM       34
#define Y7_GPIO_NUM       39
#define Y6_GPIO_NUM       36
#define Y5_GPIO_NUM       21
#define Y4_GPIO_NUM       19
#define Y3_GPIO_NUM       18
#define Y2_GPIO_NUM        5
#define VSYNC_GPIO_NUM    25
#define HREF_GPIO_NUM     23
#define PCLK_GPIO_NUM     22
// default camera settings (modifiable from config file)
int8_t brightness = 0;
int8_t contrast = 0;
int8_t saturation = 0;
uint8_t specialEffects = 0;
uint8_t whiteBalance = 1;
uint8_t awbGain = 1;
uint8_t wbMode = 0;
uint8_t exposureCtrl = 0;
uint8_t aec2 = 0;
int8_t aeLevel = 0;
uint16_t aecValue = 1200;
uint8_t gainCtrl = 1;
uint8_t agcGain = 0;
uint8_t gainCeiling = 0;
uint8_t bpc = 0;
uint8_t wpc = 1;
uint8_t rawGma = 1;
uint8_t lenc = 1;
uint8_t hmirror = 0;
uint8_t vflip = 0;
uint8_t dcw = 1;
uint8_t colorbar = 0; 
uint8_t jpegQuality = 10;
// timing config options
uint16_t timeBetweenTriggers = 60; // in seconds
uint16_t capturesPerTrigger = 3;
// device ID
String deviceID = "cam1";
// photo information
String photosDir = "/photos";
String photoName = "starlingcam"; // start of the name of each photo being saved
String sampleName = "sample";
/* camera-control.ino prototypes */
bool configESPCamera();
bool takeNewPhoto(String thisPhotoDir, String thisPhotoName);
bool nextPhoto();



/* DEEP SLEEP */
#define PIR_RF_BITMASK 0b10000000010100 // = GPIO2(RTC12) + GPIO4(RTC10) + GPIO13(RTC14) = 2^1 + 2^3
#define PIR_BITMASK 0x10100 // GPIO2 + GPIO4
#define RF_BITMASK 0b10000000000000 // GPIO13
#define PIR_1_PIN 2 // note - must also change RTC deinit in sleep deinit
#define PIR_2_PIN 4
#define RF_PIN 13
/* sleep.ino prototypes */
void timerRFSleep(uint16_t time);
void pirRFSleep();
uint8_t deepSleepAwakenPin();
void deinitSleep();

/* START SETUP AND LOOP MAIN */
#ifndef UNIT_TESTS
void setup() {
  // Disable brownout detector
  WRITE_PERI_REG(RTC_CNTL_BROWN_OUT_REG, 0);

  #if defined(DEBUG) || defined(ATPS)
  Serial.begin(115200);
  while (!Serial) {
    sleep(200);
  }
  #endif
  #ifdef ATPS // sleep to allow time to trigger GPIO1 switch
  sleep(5000);
  #endif
  esp_sleep_wakeup_cause_t wakeupReason = esp_sleep_get_wakeup_cause();
  deinitSleep(); // TODO: Is there a chance this could mess checking the awakening pin?
  if (wakeupReason == ESP_SLEEP_WAKEUP_TIMER) {
    #ifdef DEBUG
    Serial.println("Awoken by timer, sleeping");
    #endif
    pirRFSleep(); // immediately go back to sleep with PIR trigger
  }
  else if (wakeupReason != ESP_SLEEP_WAKEUP_EXT1) {
    #ifdef DEBUG
    Serial.println("Not awoken by deep sleep, sleeping");
    #endif
    pirRFSleep();
  }
  // Start Serial Monitor
  uint8_t awakenPin = deepSleepAwakenPin();

  switch(awakenPin) {
    case PIR_1_PIN:
    case PIR_2_PIN:
      triggerCapture();
      break;
    case RF_PIN:
      triggerTransmitter();
      break;
  }
}

void loop() {
  vTaskDelete(NULL);
  // actual operation loop is inside the different trigger modes in main-tasks
}
#endif
/* END SETUP AND LOOP MAIN */

/* START UNIT TESTING */
#ifdef UNIT_TESTS
// choose the correct define to run the desired test
// #define CONFIG_TEST // test status - PASSED
// #define FILE_SENT_TEST // test status - PASSED, possible changes incoming
// #define READ_NUM_IMAGES_TEST // test status - PASSED
// #define TAKE_PHOTO_TEST // test status - PASSED
// #define MANY_PHOTOS_TEST // test status - PASSED
// #define SEND_ALL_FILES_TEST // test status - PASSED
// #define UPLOAD_TO_PI_TEST // test status - PASSED
// #define UPDATE_CONFIG_TEST // test status - PASSED
// #define CAMERA_QUALITY_TESTING
// #define SEND_METADATA_TEST
#define TRANSMITTER_MODE_TEST
// #define CAPTURE_MODE_TEST
/* still to run:
  Each instruction individually
  trigger capture mode
  trigger transmitter mode
  deep sleep things
*/

#ifdef MANY_PHOTOS_TEST
uint32_t photoNum = 0;
#endif
void setup() {
  WRITE_PERI_REG(RTC_CNTL_BROWN_OUT_REG, 0);
  // Start Serial Monitor
  #ifdef DEBUG
  Serial.begin(115200);
  while (!Serial) {
    delay(200);
  }
  Serial.println("Started serial monitor");
  #endif

  #ifdef CONFIG_TEST
  initMicroSDCard();
  loadFromConfig();
  #endif

  #ifdef FILE_SENT_TEST
  initMicroSDCard();
  loadFromConfig();

  WiFi.mode(WIFI_STA);
  WiFi.begin(ssid, password);
  #ifdef DEBUG
  Serial.print("Connecting to wifi...");
  #endif
  while(WiFi.status() != WL_CONNECTED) {
    delay(300);
    #ifdef DEBUG
    Serial.print(".");
    #endif
  }
  #ifdef DEBUG
  Serial.println("");
  #endif
  String filePath = "/sample.jpeg";
  #ifdef DEBUG
  Serial.println(serverAddress);
  #endif
  sendAndDeleteImage(filePath);
  #endif // end FILE_SENT_TEST

  #ifdef READ_NUM_IMAGES_TEST
  initMicroSDCard();
  #endif // end READ_NUM_IMAGES_TEST

  #ifdef TAKE_PHOTO_TEST
  initMicroSDCard();
  configESPCamera();
  takeNewPhoto(String("/sampleCam.jpeg"));
  Serial.println("Taken photo...hopefully");
  #endif // end TAKE_PHOTO_TEST

  #ifdef MANY_PHOTOS_TEST
  initMicroSDCard();
  configESPCamera();
  #endif // end MANY_PHOTOS_TEST

  #ifdef SEND_ALL_FILES_TEST
  initMicroSDCard();
  loadFromConfig();
  WiFi.mode(WIFI_STA);
  WiFi.begin(ssid, password);
  #ifdef DEBUG
  Serial.println(ssid);
  Serial.println(password);
  Serial.print("Connecting to wifi...");
  #endif
  while(WiFi.status() != WL_CONNECTED) {
    delay(300);
    #ifdef DEBUG
    Serial.print(".");
    #endif
  }
  uint32_t successNum = sendAllPhotos();
  #ifdef DEBUG
  Serial.println(successNum);
  #endif
  #endif // end SNED_ALL_FILES_TEST

  #ifdef UPLOAD_TO_PI_TEST
  initMicroSDCard();
  loadFromConfig();
  WiFi.mode(WIFI_STA);
  WiFi.begin(ssid, password);
  #ifdef DEBUG
  Serial.println(ssid);
  Serial.println(password);
  Serial.print("Connecting to wifi...");
  #endif
  while(WiFi.status() != WL_CONNECTED) {
    delay(300);
    #ifdef DEBUG
    Serial.print(".");
    #endif
  }
  #endif // end UPLOAD_TO_PI_TEST

  #ifdef UPDATE_CONFIG_TEST
  initMicroSDCard();
  loadFromConfig();
  initWiFi();
  #ifdef DEBUG
  Serial.println(updateConfig());
  // check SD card to see if it contains the updated config file
  #endif
  #endif // end UPDATE_CONFIG_TEST

  #ifdef CAMERA_QUALITY_TESTING
  initMicroSDCard();
  loadFromConfig();
  configESPCamera();

  #ifdef DEBUG
  Serial.println("Made it past config");
  Serial.println("Config:");
  Serial.println(brightness);
  Serial.println(contrast);
  Serial.println(saturation);
  #endif

  takeNewPhoto(configDir, sampleName);
  #endif // end CAMERA_QUALITY_TESTING

  #ifdef SEND_METADATA_TEST
  initMicroSDCard();
  loadFromConfig();
  configESPCamera();
  initWiFi();
  handleInstruction(SEND_METADATA);
  #endif // end SEND_METADATA_TEST

  #ifdef TRANSMITTER_MODE_TEST
  triggerTransmitter();
  #endif // end TRANSMITTER_MODE_TEST

  #ifdef CAPTURE_MODE_TEST
  triggerCapture();
  #endif
}

void loop() {
  #ifdef CONFIG_TEST
  Serial.println(ssid); // should be changed
  Serial.println(password); // should be changed
  Serial.println(brightness); // should be changed
  Serial.println(contrast); // should be default
  Serial.println(saturation); // should be default
  Serial.println(aecValue); // should be default
  delay(5000);
  #endif // end CONFIG_TEST

  #ifdef READ_NUM_IMAGES_TEST
  Serial.println("Starting test");
  uint32_t num = getNumPhotos();
  Serial.println(num);
  setNumPhotos(num);
  delay(5000);
  #endif // end READ_NUM_IMAGES_TEST

  #ifdef MANY_PHOTOS_TEST
  uint32_t nextPhotoNum = getNumPhotos();
  if (nextPhoto()) {
    Serial.println("Next photo taken");
    Serial.print("Photo num: ");
    Serial.println(nextPhotoNum);
  }
  else{
    Serial.println("Problem taking next photo");
  }
  #endif

  #ifdef UPLOAD_TO_PI_TEST
  int16_t responseCode = sendPhoto(String("sample.jpeg"));
  #ifdef DEBUG
  Serial.print("Response code: ");
  Serial.println(responseCode);
  #endif
  delay(5000);
  #endif // end UPLOAD_TO_PI_TEST

}
#endif
/* END UNIT TESTING */

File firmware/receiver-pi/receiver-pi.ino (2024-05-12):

// #define DEBUG

#ifdef DEBUG
// put any smaller debug expressions in here
#endif

// #define UNIT_TESTS

#include <WiFi.h>
#include <AsyncWebServer_RP2040W.h>
#include <SPI.h>
#include <SD.h>

#include <Arduino.h>
#include <Wire.h>
#include <LiquidCrystal_PCF8574.h>

/* LCD */
char loading[4][2] = {"[","|","]","|"};
uint8_t loadingIdx = 0;
uint32_t prevLoadingMillis = 0;
int8_t menuPos = 0;

const char rootMenuLen = 5;
const char rootMenu[rootMenuLen][15] = {
  "GET METADATA",
  "SEND CONFIG",
  "GET PHOTOS",
  "SAMPLE PHOTO",
  "EXIT"
};

LiquidCrystal_PCF8574 lcd(0x27);
// prototypes
bool initLCD();
void showMenu(int8_t scroll);
void showLoading();
void clearBottom();
void showSent();
void updateUI();

/* SD */
// SPI pins
const int _MOSI = 19;
const int _SCK = 18;
const int _CS = 17;
const int _MISO = 16;

// sd-contro.ino prototypes
bool initMicroSDCard();
bool checkAndCreateDir(String dirPath);

/* WEB SERVER */
const char ssid[] = "starling-hub";
const char password[] = "ilovestarlings";
AsyncWebServer server(8080);
File receivedFile;
// request-handlers.ino prototypes
void setupHandlers();
void handleRoot(AsyncWebServerRequest *request);
void handleNotFound(AsyncWebServerRequest *request);
void printWifiStatus();
bool handlePhotoUpload(AsyncWebServerRequest *request, uint8_t *data, size_t len, size_t index, size_t total, bool sample=false);
void handleFileUpload(AsyncWebServerRequest *request);
bool handleNextInstruction(AsyncWebServerRequest *request);
bool handleUpdateConfig(AsyncWebServerRequest *request);

/* GENERAL */
String instructions[] = {"sendMetadata", "updateConfig", "sendPhotos", "samplePhoto", "exit", "wait"};
volatile bool instructionSent = true;
volatile bool instructionComplete = true;
volatile bool oldInstructionSent = true;
volatile bool oldInstructionComplete = true;
typedef enum{
  SEND_METADATA = 0,
  UPDATE_CONFIG = 1,
  SEND_PHOTOS = 2, 
  SAMPLE_PHOTO = 3,
  EXIT = 4, 
  WAIT = 5
  // room to add more if necessary
} t_instruction;
t_instruction intToInstruction(int i) {
  switch (i%(WAIT+1)) {
    case 0:
      return SEND_METADATA;
    case 1:
      return UPDATE_CONFIG;
    case 2:
      return SEND_PHOTOS;
    case 3:
      return SAMPLE_PHOTO;
    case 4:
      return EXIT;
    case 5:
      return WAIT;
  }
  return WAIT;
}
t_instruction currentInstruction = WAIT;


/* BUTTONS */
typedef enum {
  CONFIRM = 0,
  UP = 1,
  DOWN = 2,
  CANCEL = 3, 
  NONE = 4
} t_actions;

t_actions action = NONE;

const uint8_t CONFIRM_PIN = 10;
const uint8_t UP_PIN = 11;
const uint8_t DOWN_PIN = 12;
const uint8_t CANCEL_PIN = 13;

uint32_t prevButtonReadMillis = 0;
const uint16_t debounceTime = 500;

void initButtons();
void getNextAction();

/* RF-LINKER */
uint32_t prevRequestMillis = 0;
uint32_t prevPingMillis = 0;
bool gpio20toggle = false;
volatile bool deviceConnected = false;
void waitForConnection();

void pingDevice();

#ifndef UNIT_TESTS // this is the production code

void setup() {
  #ifdef DEBUG
  Serial.begin(115200);
  while (!Serial) {
    delay(200);
  }
  Serial.println("Initialised Serial monitor");
  #endif
  initWiFi();
  if (!initMicroSDCard()) return;
  if (!initLCD()) return;
  setupHandlers();
  initButtons();
  showMenu(0);
  pinMode(20, OUTPUT); // GPIO20 for RF linker
  waitForConnection();

}

void loop() {
  updateUI();
  if (millis() - prevRequestMillis > 30000) { // no connection for 30 seconds...
    deviceConnected = false;
    waitForConnection();
  }
}
#endif // end production code

#ifdef UNIT_TESTS // Unit test code

// #define SD_COPY_TEST // test status - PASSED
// #define LCD_DISPLAY_TEST // test status - PASSED
// #define FILE_UPLOAD_TEST // test status - PASSED
// #define MENU_TEST // test status - PASSED
// #define SERVER_ENDPOINTS_TEST test status - PASSED

#ifdef MENU_TEST
uint32_t dummyMillis = 0;
uint32_t prevInstructionSentDummy = true;
void dummyInstructionSent() {
  if (!instructionSent && prevInstructionSentDummy) {
    dummyMillis = millis();
    prevInstructionSentDummy = false;
    return;
  }
  if (!instructionSent && millis() - dummyMillis > 10000) {
    instructionSent = true;
    prevInstructionSentDummy = true;
  }
}

#endif
void setup() {
  #ifdef DEBUG
  Serial.begin(115200);
  while (!Serial) {
    delay(200);
  }
  Serial.println("Unit test has begun");
  #endif

  #ifdef SD_COPY_TEST
  initMicroSDCard();

  File origFile = SD.open("/sample.jpeg");
  uint32_t fileLen = origFile.size();
  uint8_t* fileBuf = (uint8_t*)malloc(fileLen);
  origFile.read(fileBuf, fileLen);
  origFile.close();

  File copyFile = SD.open("/copy.jpeg", FILE_WRITE);
  copyFile.write(fileBuf, fileLen);
  copyFile.close();
  #ifdef DEBUG
  Serial.println("Done");
  #endif
  #endif // end SD_COPY_TEST

  #ifdef LCD_DISPLAY_TEST
  
  int error;
  Wire.begin();
  Wire.beginTransmission(0x27);
  error = Wire.endTransmission();
  #ifdef DEBUG
  Serial.print("Error: ");
  Serial.print(error);
  #endif

  if (error == 0) {
    #ifdef DEBUG
    Serial.println(": LCD found.");
    #endif
    lcd.begin(16, 2);  // initialize the lcd

  } else {
    #ifdef DEBUG
    Serial.println(": LCD not found.");
    #endif
  }
  #endif // end LCD_DISPLAY_TEST

  #ifdef FILE_UPLOAD_TEST
  WiFi.mode(WIFI_AP);

  WiFi.softAP(ssid, password);

  while(WiFi.status() != WL_CONNECTED) {
    delay(300);
  }

  #ifdef DEBUG
  Serial.print("AP started with IP:");
  Serial.println(WiFi.softAPIP());
  #endif
  initMicroSDCard();
  setupHandlers();
  #endif // end FILE_UPLOAD_TEST

  #ifdef MENU_TEST
  initLCD();
  initButtons();
  showMenu(0);
  #ifdef DEBUG
  Serial.println("Finished init");
  #endif
  #endif // end MENU_TEST

  #ifdef SERVER_ENDPOINTS_TEST
  initWiFi();
  initMicroSDCard();
  setupHandlers();

  currentInstruction = SAMPLE_PHOTO; // change this to test each instruction
  #endif // end SERVER_ENDPOINTS_TEST
}

void loop() {
  #ifdef LCD_DISPLAY_TEST
  lcd.setBacklight(255);
  lcd.home();
  lcd.clear();
  lcd.print("LCD test");
  delay(1000);
  lcd.print("!");
  delay(1000);
  #endif

  #ifdef MENU_TEST
  updateUI();
  dummyInstructionSent();
  #endif
}
#endif // end unit test code

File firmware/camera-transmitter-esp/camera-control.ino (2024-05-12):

// function for configuring the camera... will have to go through and choose good config values
bool configESPCamera() {
  // Configure Camera parameters
 
  // Object to store the camera configuration parameters
  camera_config_t config;

  // Assign pin numbers 
  config.ledc_channel = LEDC_CHANNEL_0;
  config.ledc_timer = LEDC_TIMER_0;
  config.pin_d0 = Y2_GPIO_NUM;
  config.pin_d1 = Y3_GPIO_NUM;
  config.pin_d2 = Y4_GPIO_NUM;
  config.pin_d3 = Y5_GPIO_NUM;
  config.pin_d4 = Y6_GPIO_NUM;
  config.pin_d5 = Y7_GPIO_NUM;
  config.pin_d6 = Y8_GPIO_NUM;
  config.pin_d7 = Y9_GPIO_NUM;
  config.pin_xclk = XCLK_GPIO_NUM;
  config.pin_pclk = PCLK_GPIO_NUM;
  config.pin_vsync = VSYNC_GPIO_NUM;
  config.pin_href = HREF_GPIO_NUM;
  config.pin_sscb_sda = SIOD_GPIO_NUM;
  config.pin_sscb_scl = SIOC_GPIO_NUM;
  config.pin_pwdn = PWDN_GPIO_NUM;
  config.pin_reset = RESET_GPIO_NUM;

  config.xclk_freq_hz = 20000000;
  config.pixel_format = PIXFORMAT_JPEG; // Choices are YUV422, GRAYSCALE, RGB565, JPEG
 
  // Select lower framesize if the camera doesn't support PSRAM
  // AI thinker should support PSRAM so this is mostly for code reuseability
  if (psramFound()) {
    config.frame_size = FRAMESIZE_UXGA; // Resolution
    config.jpeg_quality = jpegQuality; //10-63 lower number = higher quality
    config.fb_count = 2;
  } else {
    config.frame_size = FRAMESIZE_SVGA;
    config.jpeg_quality = 12;
    config.fb_count = 1;
  }
 
  // Initialize the Camera
  esp_err_t err = esp_camera_init(&config);
  if (err != ESP_OK) {
    #ifdef DEBUG
    Serial.print("Camera init failed");
    #endif
    return false;
  }
 
  // Camera quality adjustments
  sensor_t * s = esp_camera_sensor_get();

  s->set_brightness(s, brightness);   // BRIGHTNESS (-2 to 2)
  s->set_contrast(s, contrast); // CONTRAST (-2 to 2)
  s->set_saturation(s, saturation);   // SATURATION (-2 to 2)
  s->set_special_effect(s, specialEffects);   // SPECIAL EFFECTS (0 - No Effect, 1 - Negative, 2 - Grayscale, 3 - Red Tint, 4 - Green Tint, 5 - Blue Tint, 6 - Sepia)
  s->set_whitebal(s, whiteBalance); // WHITE BALANCE (0 = Disable , 1 = Enable)
  s->set_awb_gain(s, awbGain); // AWB GAIN (0 = Disable , 1 = Enable)
  s->set_wb_mode(s, wbMode); // WB MODES (0 - Auto, 1 - Sunny, 2 - Cloudy, 3 - Office, 4 - Home)
  s->set_exposure_ctrl(s, exposureCtrl);   // EXPOSURE CONTROLS (0 = Disable , 1 = Enable)
  s->set_aec2(s, aec2);   // AEC2 (0 = Disable , 1 = Enable)
  s->set_ae_level(s, aeLevel);   // AE LEVELS (-2 to 2)
  s->set_aec_value(s, aecValue);   // AEC VALUES (0 to 1200)
  s->set_gain_ctrl(s, gainCtrl);   // GAIN CONTROLS (0 = Disable , 1 = Enable)
  s->set_agc_gain(s, agcGain);   // AGC GAIN (0 to 30)
  s->set_gainceiling(s, (gainceiling_t)0);   // GAIN CEILING (0 to 6)
  s->set_bpc(s, bpc);   // BPC (0 = Disable , 1 = Enable)
  s->set_wpc(s, wpc);   // WPC (0 = Disable , 1 = Enable)
  s->set_raw_gma(s, rawGma);   // RAW GMA (0 = Disable , 1 = Enable)
  s->set_lenc(s, lenc);   // LENC (0 = Disable , 1 = Enable)
  s->set_hmirror(s, hmirror);   // HORIZ MIRROR (0 = Disable , 1 = Enable)
  s->set_vflip(s, vflip);   // VERT FLIP (0 = Disable , 1 = Enable)
  s->set_dcw(s, dcw);   // DCW (0 = Disable , 1 = Enable)
  s->set_colorbar(s, colorbar);   // COLOR BAR PATTERN (0 = Disable , 1 = Enable)

  return true;
}

bool nextPhoto() {
  // Check for photo directory and create if necessary
  if (!checkAndCreateDir(photosDir)) {
    #ifdef DEBUG
    Serial.println("Failed to create photo DIR");
    #endif
    return false;
  }

  fs::FS &fs = SD_MMC;

  File photosDirFile = fs.open(photosDir.c_str());

  if (!photosDirFile) {
    #ifdef DEBUG
    Serial.println("Failed to open Photos DIR");
    #endif
    return false;
    // this is a major fail, because we should have just created the DIR...
  }

  if (!photosDirFile.openNextFile()) { // photos DIR is empty
    if (!checkAndCreateDir(configDir)) {
      #ifdef DEBUG
      Serial.println("Failed to create config DIR");
      #endif
      return false;
    }
    #ifdef DEBUG
    Serial.println("Empty photos directory - re-initialising num photos");
    #endif
    deleteAndRecreateNumPhotos(); // re-initialise the number of photos taken
  }
  photosDirFile.close();

  uint32_t nextNum = getNumPhotos() + 1;
  
  if (!setNumPhotos(nextNum)) {
    #ifdef DEBUG
    Serial.println("Failed to set next num photos");
    #endif
    return false;
  }

  return takeNewPhoto(photosDir, photoName + String(nextNum));
}

// for taking a new photo
bool takeNewPhoto(String thisPhotoDir, String thisPhotoName) {
  // Take Picture with Camera
  if (!checkAndCreateDir(thisPhotoDir)) {
    #ifdef DEBUG
    Serial.println("Failed to create this photo DIR");
    #endif
    return false;
  }

  String path = thisPhotoDir + String("/") + thisPhotoName + String(".jpeg");
  // Setup frame buffer
  camera_fb_t  * fb = esp_camera_fb_get();
 
  if (!fb) {
    #ifdef DEBUG
    Serial.println("Camera capture failed");
    #endif
    return false;
  }
 
  // Save picture to microSD card
  fs::FS &fs = SD_MMC;
  File file = fs.open(path.c_str(), FILE_WRITE);
  if (!file) {
    #ifdef DEBUG
    Serial.println("Failed to open file in write mode");
    #endif
    return false;
  }

  file.write(fb->buf, fb->len); // payload (image), payload length

  // Close the file
  file.close();
 
  // Return the frame buffer back to the driver for reuse
  esp_camera_fb_return(fb);

  // return true (for success!)
  return true;
}

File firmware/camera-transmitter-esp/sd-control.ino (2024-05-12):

// init the SD card
bool initMicroSDCard() {
  // Start the MicroSD card

  // enable GPIO1 which disables the PNP switches
  // GPIO1 is also used for UART so cannot use in DEBUG mode
  #if !defined(DEBUG) && !defined(ATPS)
  pinMode(1, OUTPUT);
  digitalWrite(1, HIGH);
  #endif
  
  #ifdef DEBUG
  Serial.println("Mounting MicroSD Card");
  #endif

  // Check for mount failure
  if (!SD_MMC.begin()) {
    #ifdef DEBUG
    Serial.println("MicroSD Card Mount Failed");
    #endif
    return false;
  }

  // check for no card
  uint8_t cardType = SD_MMC.cardType();
  if (cardType == CARD_NONE) {
    
    Serial.println("No MicroSD Card found");
    return false;
  }

  #ifdef DEBUG
  Serial.println("Made it past SD card mounting");
  #endif

  return true;
}

bool deleteAndRecreateNumPhotos() {
  fs::FS &fs = SD_MMC;
  fs.remove(numPhotosPath.c_str()); // remove any existing file /directory
  File numPhotosFile = fs.open(numPhotosPath.c_str(), FILE_WRITE); // open new file for writing
  // if it fails to open this file in write mode... the same photo file will be overwritten again and again
  if (numPhotosFile) {
    numPhotosFile.print(newNumPhotosJson);
    numPhotosFile.close();
    return true;
  }
  numPhotosFile.close();
  return false;
}

bool checkAndCreateDir(String dirPath) {
  fs::FS &fs = SD_MMC;

  // Check for photo directory and create if necessary
  File dirFile = fs.open(dirPath.c_str(), FILE_READ);

  if (!dirFile) {
    #ifdef DEBUG
    Serial.println("No dir... creating");
    #endif
    dirFile.close();
    if (!fs.mkdir(dirPath.c_str())) {
      return false;
    };
  }
  else if (!dirFile.isDirectory()) {
    #ifdef DEBUG
    Serial.println("Photo dir is a file... removing and creating dir");
    #endif
    dirFile.close();
    if (!fs.remove(dirPath.c_str())) {
      return false;
    };
    if (!fs.mkdir(dirPath.c_str())) {
      return false;
    };
  }

  return true;
}

bool setNumPhotos(uint32_t numPhotos) {
  if (!checkAndCreateDir(configDir)) {
    #ifdef DEBUG
    Serial.println("Couldn't create config DIR");
    #endif
    // this is a major fail...
    return false;
  }
  
  fs::FS &fs = SD_MMC;
  File numPhotosFile = fs.open(numPhotosPath.c_str(), FILE_WRITE);
  
  // if this doesn't open correctly, not much we can do... will just have to try again next time

  // create numphotos file from scratch if necessary
  if (!numPhotosFile || numPhotosFile.isDirectory() || numPhotosFile.size() >32 ) {
    #ifdef DEBUG
    Serial.println("numphotos invalid... creating new");
    #endif
    numPhotosFile.close();
    deleteAndRecreateNumPhotos();
    numPhotosFile = fs.open(numPhotosPath.c_str(), FILE_WRITE); // re-open
  }


  // Create JSON doc and object
  JsonDocument numPhotosDoc;
  // JsonObject numPhotosObj = numPhotosDoc.as<JsonObject>();

  numPhotosDoc["numPhotos"] = numPhotos; // save to JSON

  #ifdef DEBUG
  Serial.print("New value stored in numPhotos doc:");
  Serial.println(numPhotosDoc["numPhotos"].as<int>());
  #endif


  // write JSON doc to file
  if (serializeJson(numPhotosDoc, numPhotosFile) == 0) {
    #ifdef DEBUG
    Serial.println("Failed to write new num photos file");
    #endif
    return false;
  }

  numPhotosFile.close();
  numPhotosDoc.clear();

  return true;
}

uint32_t getNumPhotos() {

  if (!checkAndCreateDir(configDir)) {
    #ifdef DEBUG
    Serial.println("Couldn't create config DIR");
    #endif
    // this is a major fail...
    return 0;
  }

  fs::FS &fs = SD_MMC;
  File numPhotosFile = fs.open(numPhotosPath.c_str(), FILE_READ);
  
  if (!numPhotosFile || numPhotosFile.isDirectory() || numPhotosFile.size() >32 ) {
    #ifdef DEBUG
    Serial.println("numphotos invalid... creating new");
    #endif
    numPhotosFile.close();
    deleteAndRecreateNumPhotos();
    return 0;
  }

  // create JsonDocument for deserialization
  JsonDocument numPhotosDoc;
  DeserializationError error = deserializeJson(numPhotosDoc, numPhotosFile);
  if (error) {
    #ifdef DEBUG
    Serial.println("deserializeJson() failed");
    #endif
    numPhotosFile.close();
    deleteAndRecreateNumPhotos();
    return 0;
  }

  uint32_t numPhotos = 0;
  JsonObject numPhotosObj = numPhotosDoc.as<JsonObject>();

  // grab current num photos
  if (numPhotosObj["numPhotos"].is<int>()) {
    #ifdef DEBUG
    Serial.println("Found a valid value for numphotos in json file");
    #endif
    if (numPhotosObj["numPhotos"] >= 0) {
      numPhotos = numPhotosObj["numPhotos"];
    }
  }

  numPhotosFile.close();
  numPhotosDoc.clear();
  return numPhotos; // will be 0 if value in json file is <0
}

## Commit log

2024-03-16 added T. P. section on consumer camera traps
2024-03-16 added power section
2024-03-16 added camera stuff
2024-04-27 Sample code
    This is some sample code for the Raspberry Pi Pico W that enables it's WiFi capabilities
2024-05-01 Added robert final report draft
    [development environment.csv, requirements.csv]
2024-05-01 Added ESP-flow.drawio
2024-05-03 Added RF linker Receiver and Transmitter
    Using an RF linker to activate the ESP out of deep sleep
    [Receiver+transmitter.kicad_pcb, Receiver+transmitter.kicad_sch, receiver.kicad_sch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]
2024-05-03 Circuitry
    LTSpice designs for LDR circuit and OR gate circuits
2024-05-03 initial commit for camera/transmitter
2024-05-03 Circuit schematics
    Made a few additions to the circuit schematic
    [transmitter.kicad_sch]
2024-05-04 thiyashan review
    Created my draft review so far
    [development environment.csv, requirements.csv]
2024-05-07 Final revision of KiCAD Docs
    Edited the transmitter and receiver schematics to reflect the recent changes
    [receiver.kicad_sch, transmitter.kicad_sch]
2024-05-10 Updated robert report
    [Receiver+transmitter.kicad_pcb, Receiver+transmitter.kicad_sch, receiver.kicad_sch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]
2024-05-10 Removed final report drafts
    [development environment.csv, requirements.csv]
2024-05-10 updated ESP-flow.png
2024-05-11 Delete sample-code/Final directory
    Deleting the old ATP files
2024-05-11 Hardware circuits
    Neatened up Thiyashan Hardware circuits
2024-05-11 Hardware circuits
    Neatened up Thiyashan Circuits
2024-05-11 Added sample photos
2024-05-12 Neatened up sample code
    Neatened up the sample code folder for easy navigation
2024-05-12 Circuit
    Edited circuits
2024-05-12 Added BOM and GA table
    Added the BOM for the hardware and edited the GA table
2024-05-12 Added Pi-flow.drawio
2024-05-12 Added Pi-flow.png
2024-05-12 Update Appendix-A1.tex
    Updated the mechanical BOM
2024-05-12 Update Power.tex
    Edited label
